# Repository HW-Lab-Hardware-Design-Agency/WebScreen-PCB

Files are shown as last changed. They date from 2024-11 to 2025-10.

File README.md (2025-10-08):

   

# WebScreen-PCB

WebScreen-PCB is the design of a printed circuit board (PCB) for the WebScreen, a display device with a custom stand. This project is developed by **HW Lab - Hardware Design Agency** and aims to optimize the integration and functionality of the WebScreen in various applications.



## Main Features
- **Optimized Design**: Compact and efficient PCB. 
- **Mounting System**: Insertion and friction-based fastening, eliminating the need for adhesives. 
- **Compatibility**: Designed to work with the [DO0200FS01 display](https://www.dwo.net.cn/pd.jsp?id=11919).
- **Connectivity**: Interfaces adapted for easy integration with other devices.
  
## Technical Specifications
- **Size**: 60.6 x 27.6 mm
- **Material**: FR-4 S1000H TG150
- **PCB Thickness**: 1.6 mm
- **Number of Layers**: 4 layers
- **Operating Voltage**: 5V (via usb)
- **Connection Interfaces**: USB / Wi-Fi / Bluetooth

## Included Files
- **Schematic**: : Circuit design in [KiCad](https://www.kicad.org/) format. 
- **PCB Layout**: Board design in Gerber format.
- **Bill of Materials (BOM)**: List of components used. 

## Installation and Usage  
1. Download the Gerber files and send them to a PCB manufacturer.  
2. Acquire the components according to the BOM.  
3. Assemble the PCB.  
4. [Integrate the PCB with the WebScreen](https://www.youtube.com/watch?v=CHH5L84EN5o&t=6s) and perform the corresponding tests.

## License
This project is open source. See the [LICENSE](https://github.com/HW-Lab-Hardware-Design-Agency/WebScreen-PCB/blob/main/LICENSE) file for details.

## PCBWay
[PCBWay](https://pcbway.com/g/j8T652) top quality PCBA service made this project possible: fast, precise, and super reliable. We highly recommend them to all creators out there, and we’ll definitely keep working with them for future builds.

## Contact
For inquiries or contributions, please contact the development team through the repository issues or via email.



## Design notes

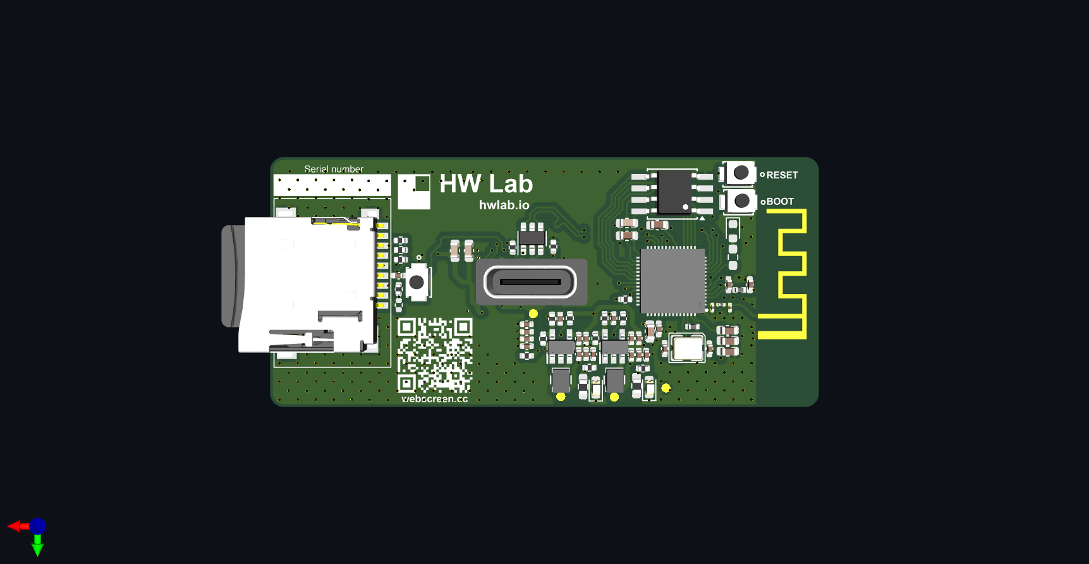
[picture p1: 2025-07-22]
WebScreen-pcba_layout_render.png

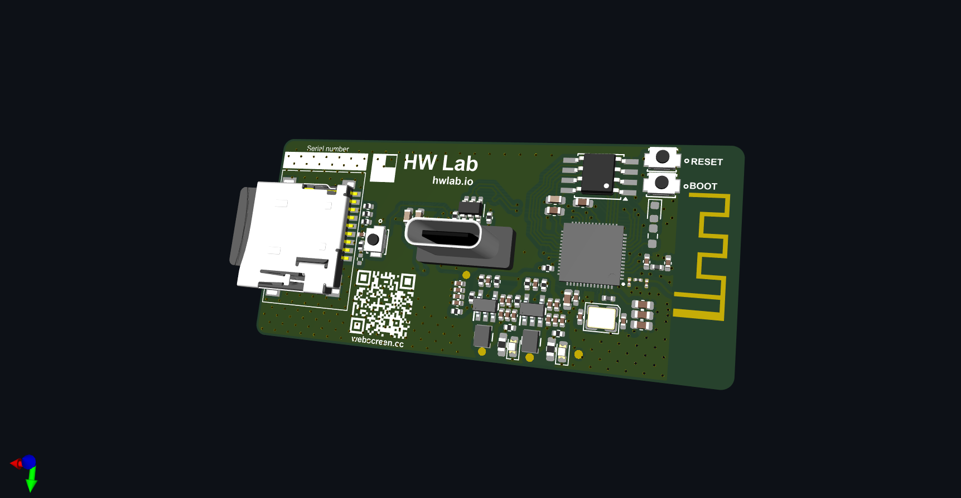
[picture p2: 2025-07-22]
WebScreen-pcba_layout_render_perspective.png

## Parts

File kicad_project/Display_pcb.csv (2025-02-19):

Reference | Value | Qty | DNP | BOM | LCSC Part # | MPN
AE1 | PCB Antenna 2.4GHz | 1
C1,C8,C9,C12,C13,C19,C23,C26,C29,C35 | 100nF | 10 |  | 35V 100nF X7R ±10% 0402 Multilayer Ceramic Capacitors MLCC - SMD/SMT ROHS | C343047 | CGA2B3X7R1V104KT0Y0F
C2,C5,C6,C7,C10,C14,C15,C20,C32,C33 | 1uF | 10 |  | 16V 1uF X5R ±10% 0603 Multilayer Ceramic Capacitors MLCC - SMD/SMT ROHS | C1592 | CL10A105KO8NNNC
C3 | 15pF | 1 |  | 16V 15pF NP0 ±10% 0402 Multilayer Ceramic Capacitors MLCC - SMD/SMT ROHS | C1852854 | CC0402KRNPO7BN150
C4 | 12pF | 1 |  | 25V 12pF null ±2% 0402 Multilayer Ceramic Capacitors MLCC - SMD/SMT ROHS | C882545 | GRM1555C1E120GA01D
C11,C18 | 10uF | 2 |  | 10V 10uF X5R ±20% 0402 Multilayer Ceramic Capacitors MLCC - SMD/SMT ROHS | C315248 | CL05A106MP5NUNC
C16,C17 | 1.8pF | 2 |  | 50V 1.8pF C0G 0201 Multilayer Ceramic Capacitors MLCC - SMD/SMT ROHS | C161415 | GRM0335C1H1R8BA01D
C21,C31 | 6.8pF | 2 |  | 50V 6.8pF C0G 0402 Multilayer Ceramic Capacitors MLCC - SMD/SMT ROHS | C1576 | 0402CG6R8C500NT
C22,C24,C25,C30,C34,C36 | 22uF | 6 |  | 10V 22uF X5R ±20% 0402 Multilayer Ceramic Capacitors MLCC - SMD/SMT ROHS | C6119813 | CGA0402X5R226M100GT
DS1,DS2,DS3 | GREEN | 3 |  | LED GREEN [0603] | C125098 | LTST-C191KGKT
IC1 | ESP32-S3R8 | 1 |  | WiFi Modules - 802.11 SMD IC, Dual-Core MCU, Wi-Fi 2.4G & BLE 5.0 Combo, 8 MB Octal SPI PSRAM, QFN 56-pin, 7*7 mm | C2913194 | ESP32-S3R8
J1 | Micro_SD_Card_Det_Hirose_DM3AT | 1 |  | -20℃~+90℃ 2mm Deck MicroSD card (TF card) Self bomb SMD SD Card / Memory Card Connector ROHS | C393941 | TF PUSH
J2 | USB C | 1 |  |  | C2894918 | HC019-1E1H1A103-0HR
J8 | 33FXRH-SM1-GAN-TF | 1 |  | SMD,P=0.6mm FFC/FPC Connectors ROHS | C2890488 | 33FXRH-SM1-GAN-TF
L1 | 22nH | 1 |  | 300mA 22nH ±5% 600mΩ 0402 Inductors (SMD) ROHS | C15178 | SDCL1005C22NJTDF
L2 | 2nH | 1 |  | 300mA 2nH 200mΩ 0402 Inductors (SMD) ROHS | C279790 | SDCL1005C2N0BTDF
L3 | 2.7nH | 1 |  | 500mA 2.7nH 200mΩ 0201 Inductors (SMD) ROHS | C98043 | LQP03TN2N7B02D
L4,L5 | 1uH | 2 |  | 1.2A 1uH ±20% 1.2A 1007 Power Inductors ROHS | C524998 | BRFL2518T1R0M
Q1,Q3 | S8050 | 2 |  | 25V 300mW 500mA NPN SOT-23 Bipolar (BJT) ROHS | C181158 | S8050
Q2 | BSS84 | 1 |  | 50V 130mA 200mW 10Ω@5V,100mA 2.5V@250uA 1 Piece P-Channel SOT-23 MOSFETs ROHS | C2926187 | IRF4905STRLP(UMW)
R1,R2,R3,R4,R12 | 10k | 5 |  | 62.5mW Thick Film Resistors 50V ±100ppm/℃ ±5% 10kΩ 0402 Chip Resistor - Surface Mount ROHS | C25531 | 0402WGJ0103TCE
R5,R6 | 4k99 | 2 |  | 62.5mW Thick Film Resistors 50V ±100ppm/℃ ±1% 4.99kΩ 0402 Chip Resistor - Surface Mount ROHS | C137965 | RC0402FR-074K99L
R7,R11,R13,R14,R30 | 100k | 5 |  | 62.5mW Thick Film Resistors 50V ±100ppm/℃ ±1% 100kΩ 0402 Chip Resistor - Surface Mount ROHS | C25741 | 0402WGF1003TCE
R9,R10 | TBD | 2
R15,R16,R23 | 1k | 3 |  | RES SMD 1k 1% [0603] | C844746 | CRCW06031K00FKEAC
R17 | 22k | 1 |  | 62.5mW Thick Film Resistors 50V ±100ppm/℃ ±1% 22kΩ 0402 Chip Resistor - Surface Mount ROHS | C25768 | 0402WGF2202TCE
R18,R19,R21,R32 | 0R | 4 |  | 62.5mW Thick Film Resistors 50V ±800ppm/℃ ±1% 0Ω 0402 Chip Resistor - Surface Mount ROHS | C17168 | 0402WGF0000TCE
R31 | 680k | 1 |  | 62.5mW Thick Film Resistors 50V ±100ppm/℃ ±1% 680kΩ 0402 Chip Resistor - Surface Mount ROHS | C163456 | RC0402FR-07680KL
SW1,SW2,SW3 | B3U-1000P | 3 |  | 2.5mm 1.6mm Round Button 50mA Brick nogging 3mm SPST 153gf 12V SMD,2.5x3mm Tactile Switches ROHS | C231329 | B3U-1000P
U1 | W25Q128JVSIQ | 1 |  | 128Mbit SOIC-8-208mil NOR FLASH ROHS | C113767 | W25Q128JVSIQ
U2,U4 | SY8089A1AAC | 2 |  | LOW LOSS POWER DISTRIBUTION SWITCH WITH | C479074 | SY8089A1AAC
U5 | USBLC6-2SC6 | 1 |  | 5A 17V 6V Unidirectional 5.25V SOT-23-6 Electrostatic and Surge Protection (TVS/ESD) ROHS | C7519 | USBLC6-2SC6
Y1 | 40MHz | 1 |  | 40MHz 贴片晶振 15pF ±10ppm ±20ppm SMD3225-4P Crystals ROHS | C9010 | X322540MPB4SI

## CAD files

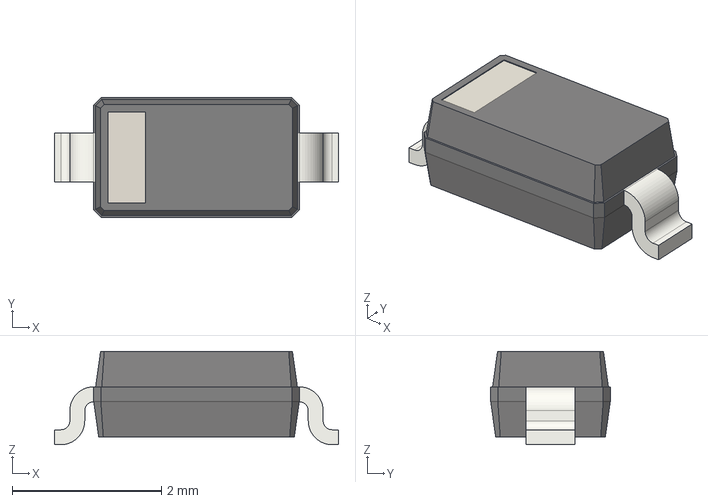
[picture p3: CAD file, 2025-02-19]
kicad_project/3Dlib/D_SOD-123.step
3.80 x 1.60 x 1.25 mm

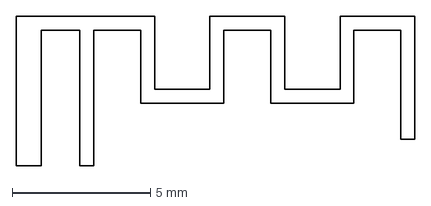
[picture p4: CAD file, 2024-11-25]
kicad_project/design_pcb_antenna/pcb_antenna_2-4GHz.dxf
14.4 x 5.40 mm

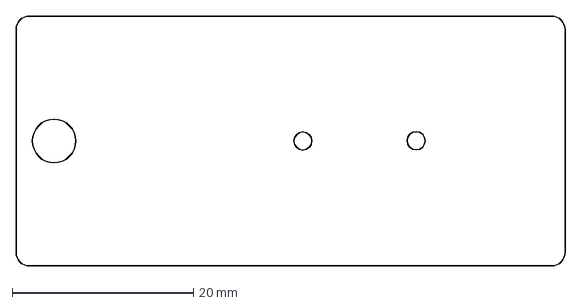
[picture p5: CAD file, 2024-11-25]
kicad_project/pcb_outline.dxf
60.6 x 27.6 mm

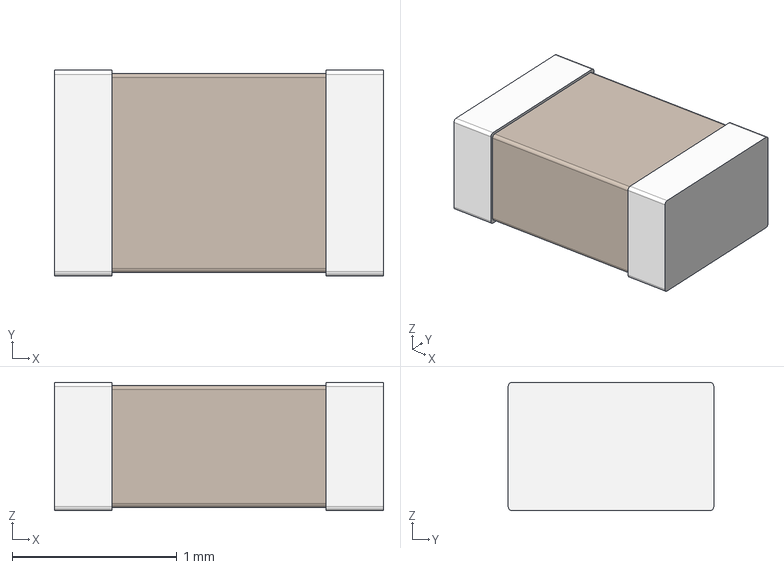
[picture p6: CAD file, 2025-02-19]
kicad_project/3Dlib/c_0805_h078.step
2.00 x 1.25 x 0.78 mm

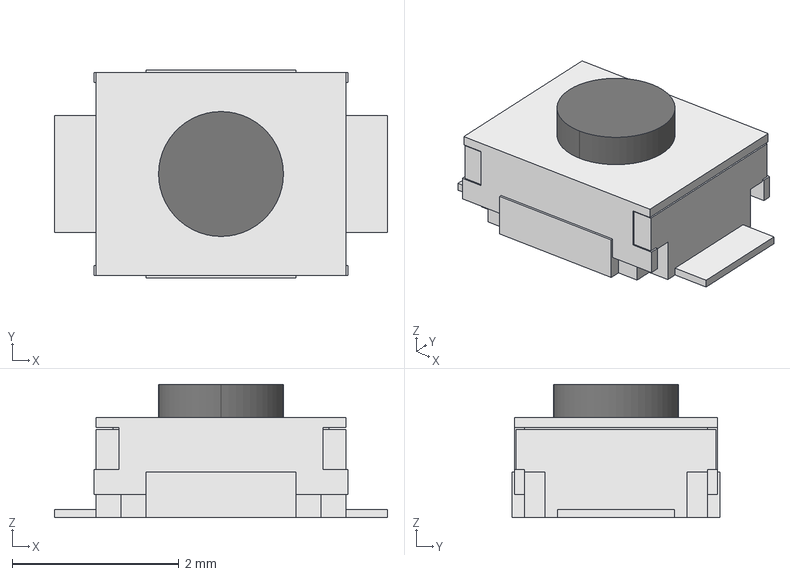
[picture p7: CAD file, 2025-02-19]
kicad_project/3Dlib/B3U_1000P.step
4.00 x 2.50 x 1.60 mm

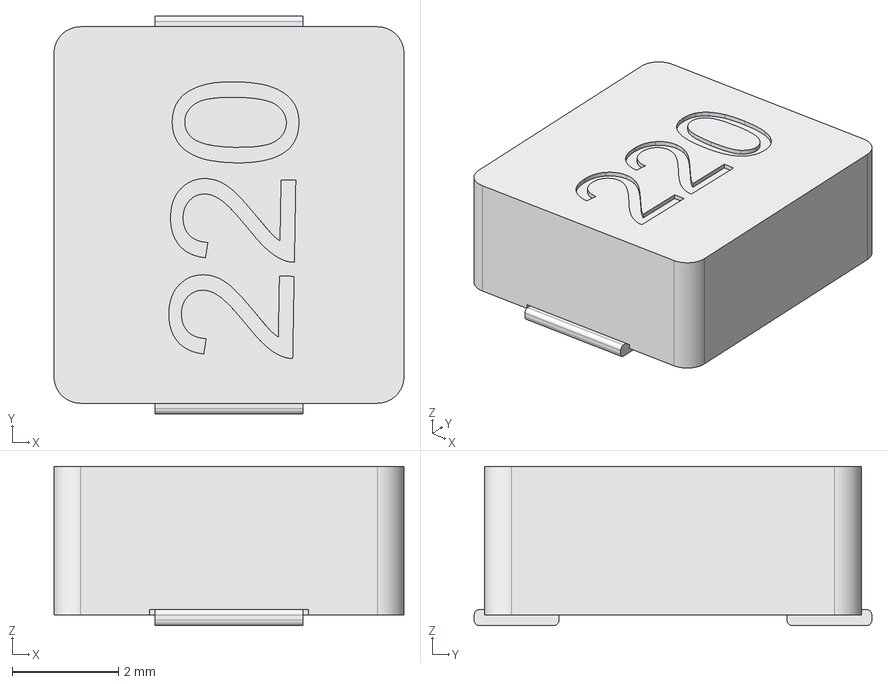
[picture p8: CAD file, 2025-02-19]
kicad_project/3Dlib/MDA7030-220M.step
6.60 x 7.50 x 3.00 mm

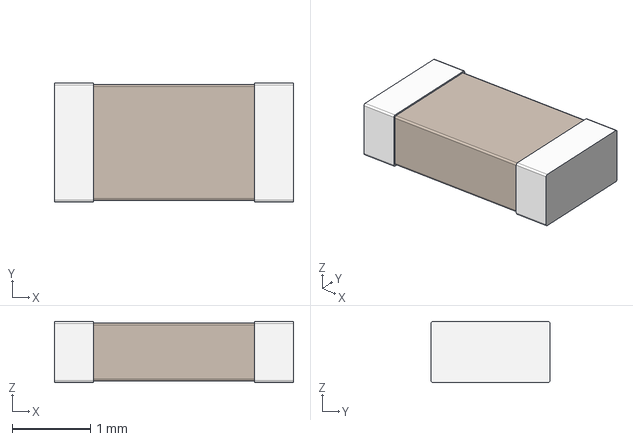
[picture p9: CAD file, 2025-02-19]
kicad_project/3Dlib/c_1206_h078.step
3.05 x 1.52 x 0.78 mm

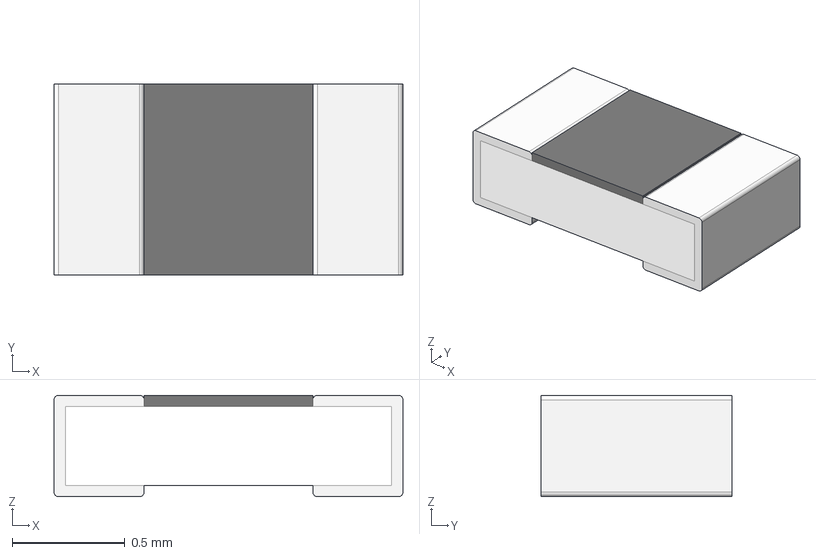
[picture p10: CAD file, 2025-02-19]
kicad_project/3Dlib/r_0603_h078.step
1.55 x 0.85 x 0.45 mm

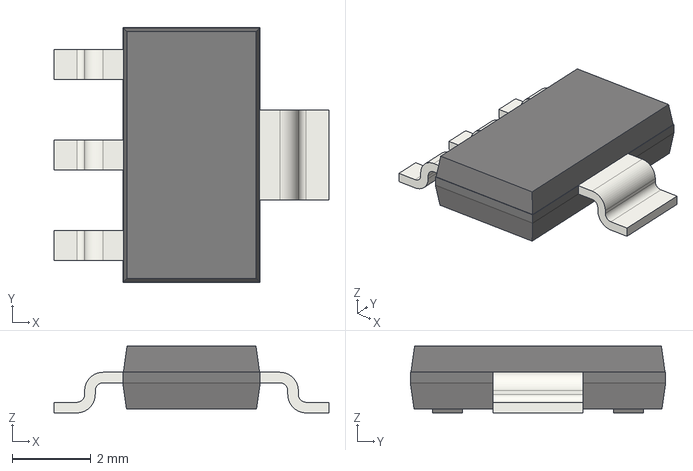
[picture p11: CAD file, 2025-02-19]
kicad_project/3Dlib/SOT-223.step
7.00 x 6.50 x 1.70 mm

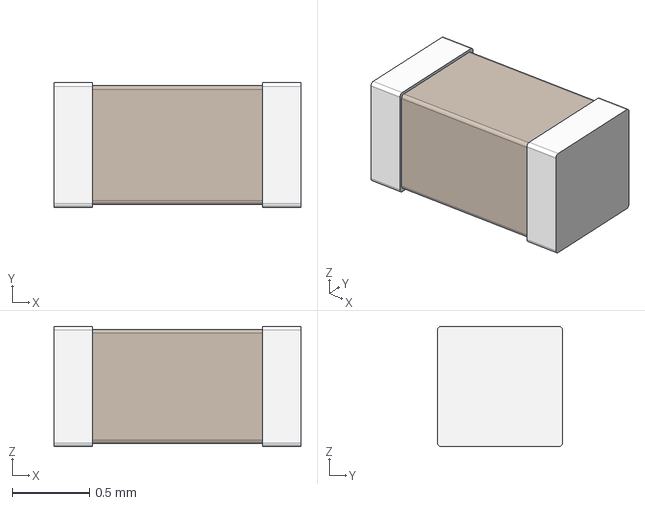
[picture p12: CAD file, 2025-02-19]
kicad_project/3Dlib/c_0603_h078.step
1.60 x 0.81 x 0.78 mm

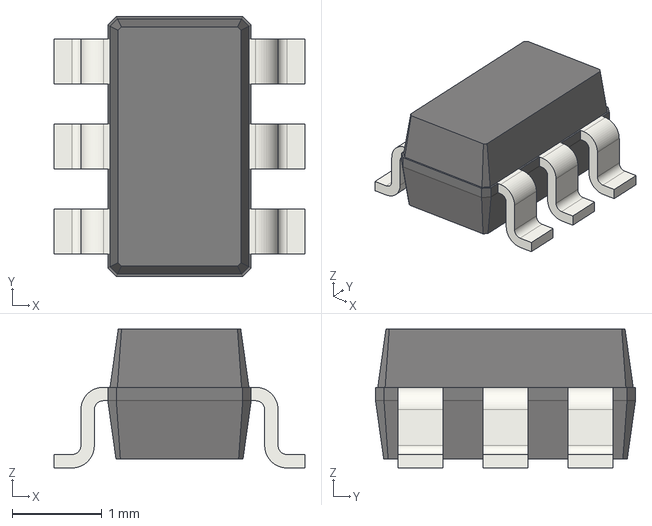
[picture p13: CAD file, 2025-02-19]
kicad_project/3Dlib/SOT-23-6.step
2.80 x 2.90 x 1.55 mm

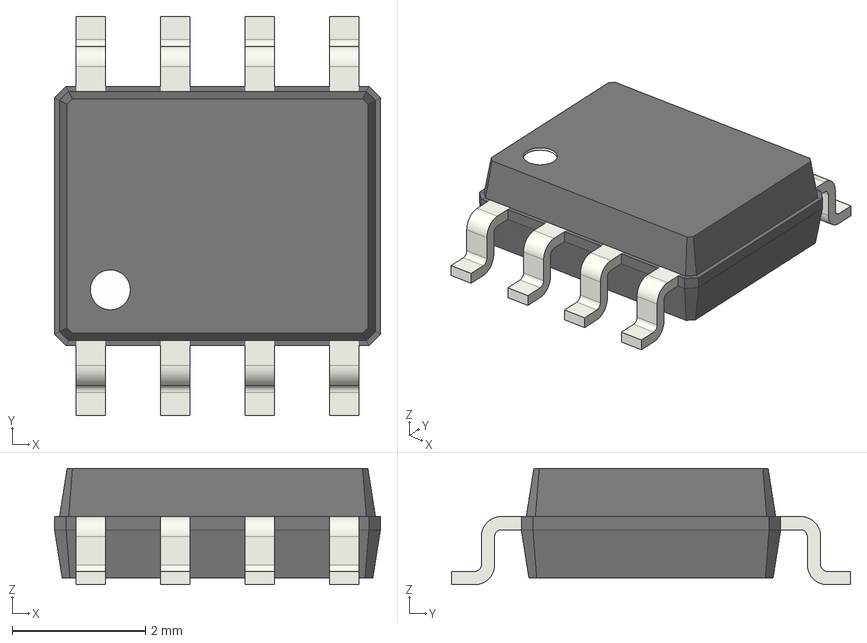
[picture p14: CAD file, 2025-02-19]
kicad_project/3Dlib/soic_8_39x49_p127.step
4.90 x 6.00 x 1.75 mm

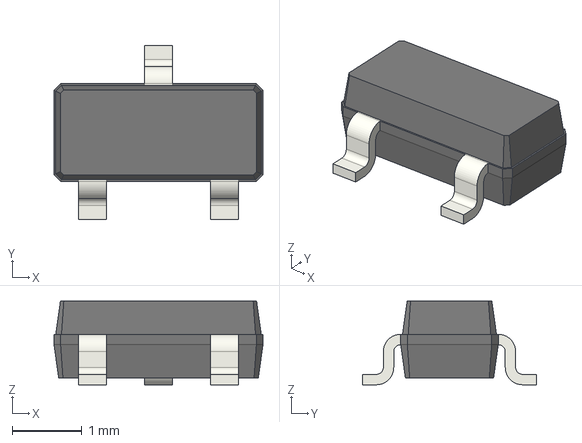
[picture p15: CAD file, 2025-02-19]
kicad_project/3Dlib/sot23_3_25x30_p095.step
3.00 x 2.50 x 1.20 mm

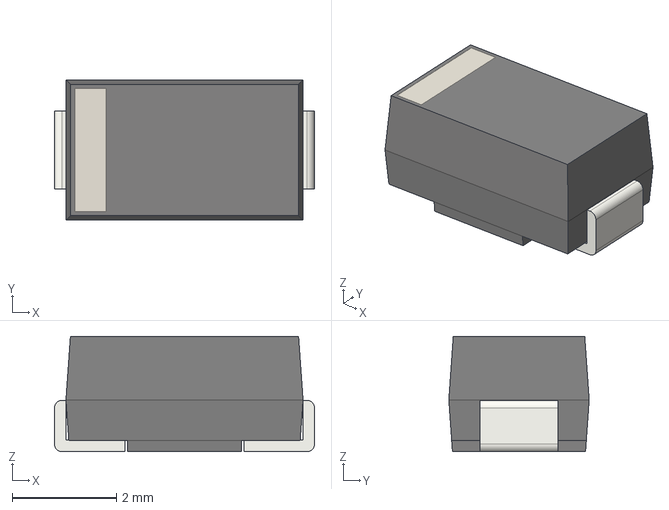
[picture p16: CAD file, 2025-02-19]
kicad_project/3Dlib/D_SMA.step
5.00 x 2.70 x 2.22 mm

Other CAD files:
kicad_project/design_pcb_antenna/antenna_footprint.FCStd
kicad_project/3Dlib/MicroSD_Socket.STEP
kicad_project/3Dlib/33FXRH-SM1-GAN-TF.STEP
kicad_project/3Dlib/L_0201_0603Metric.step
kicad_project/3Dlib/AXPM65611.step
kicad_project/3Dlib/BRFL2518T1R0M.STEP
kicad_project/3Dlib/C_0201_0603Metric.step
kicad_project/3Dlib/C_0402_1005Metric.step
kicad_project/3Dlib/Crystal_SMD_3225-4Pin_3.2x2.5mm.step
kicad_project/3Dlib/DFE252012P-1R0M=P2.STEP
kicad_project/3Dlib/ESP32-S3R8.stp
kicad_project/3Dlib/L_0402_1005Metric.step
kicad_project/3Dlib/SY8089A1AAC.stp
kicad_project/3Dlib/USB_C_HC019-1E1H1A103-0HR.step
kicad_project/3Dlib/c_1206_h160.step
kicad_project/3Dlib/c_1210.step
kicad_project/3Dlib/led_0603.step
kicad_project/3Dlib/r_0402_h040.step

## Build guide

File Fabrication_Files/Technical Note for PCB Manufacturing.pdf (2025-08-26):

Technical Note for PCB Manufacturing

Dear team,
Please take into consideration the following points regarding this design:
1. SD Card Reader
The SD card reader connector extends beyond the PCB outline. This condition is intentional and must be respected during assembly and quality control.

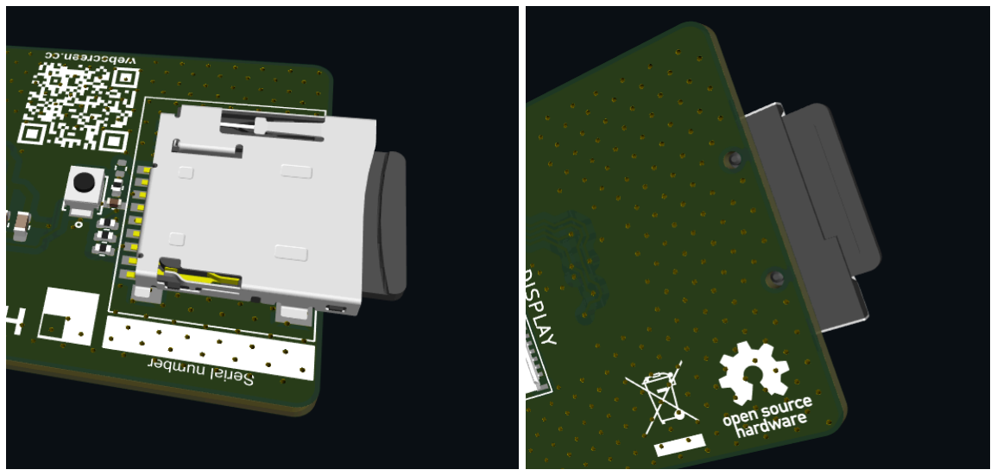
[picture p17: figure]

2. J8 Connector
The J8 connector includes two additional pads to ensure compatibility with similar connector models. These extra pads must be preserved and processed as standard pads, without modification.

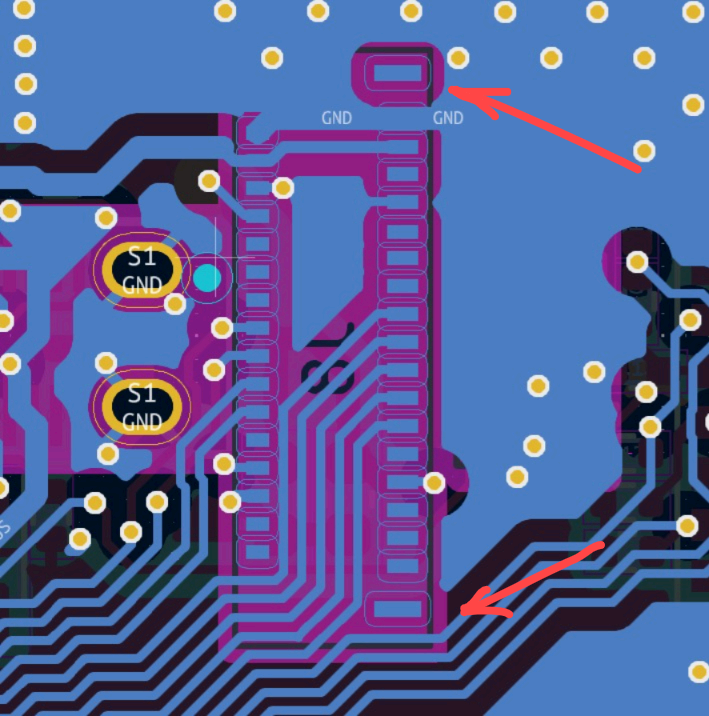
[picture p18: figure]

3. Antenna
The antenna area must remain free of solder and solder paste. In the manufacturing files, the F.Paste layer correctly indicates that no solder paste should be applied in this region. Please verify this before assembly.

### 4. Vias

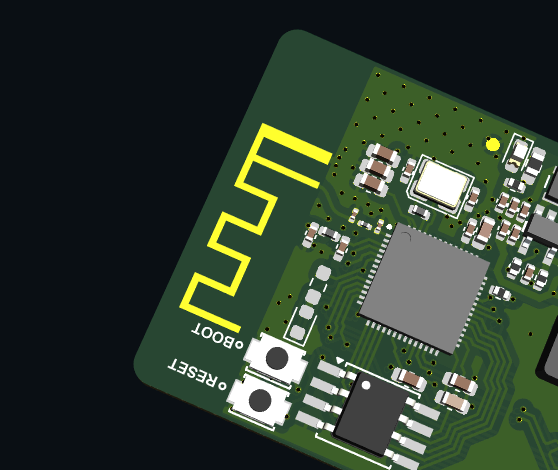
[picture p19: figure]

All vias must be resin-filled and capped to improve reliability and ensure proper solder mask coverage.

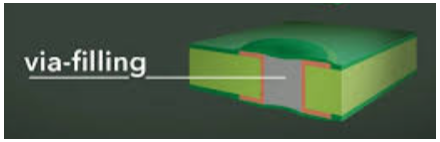
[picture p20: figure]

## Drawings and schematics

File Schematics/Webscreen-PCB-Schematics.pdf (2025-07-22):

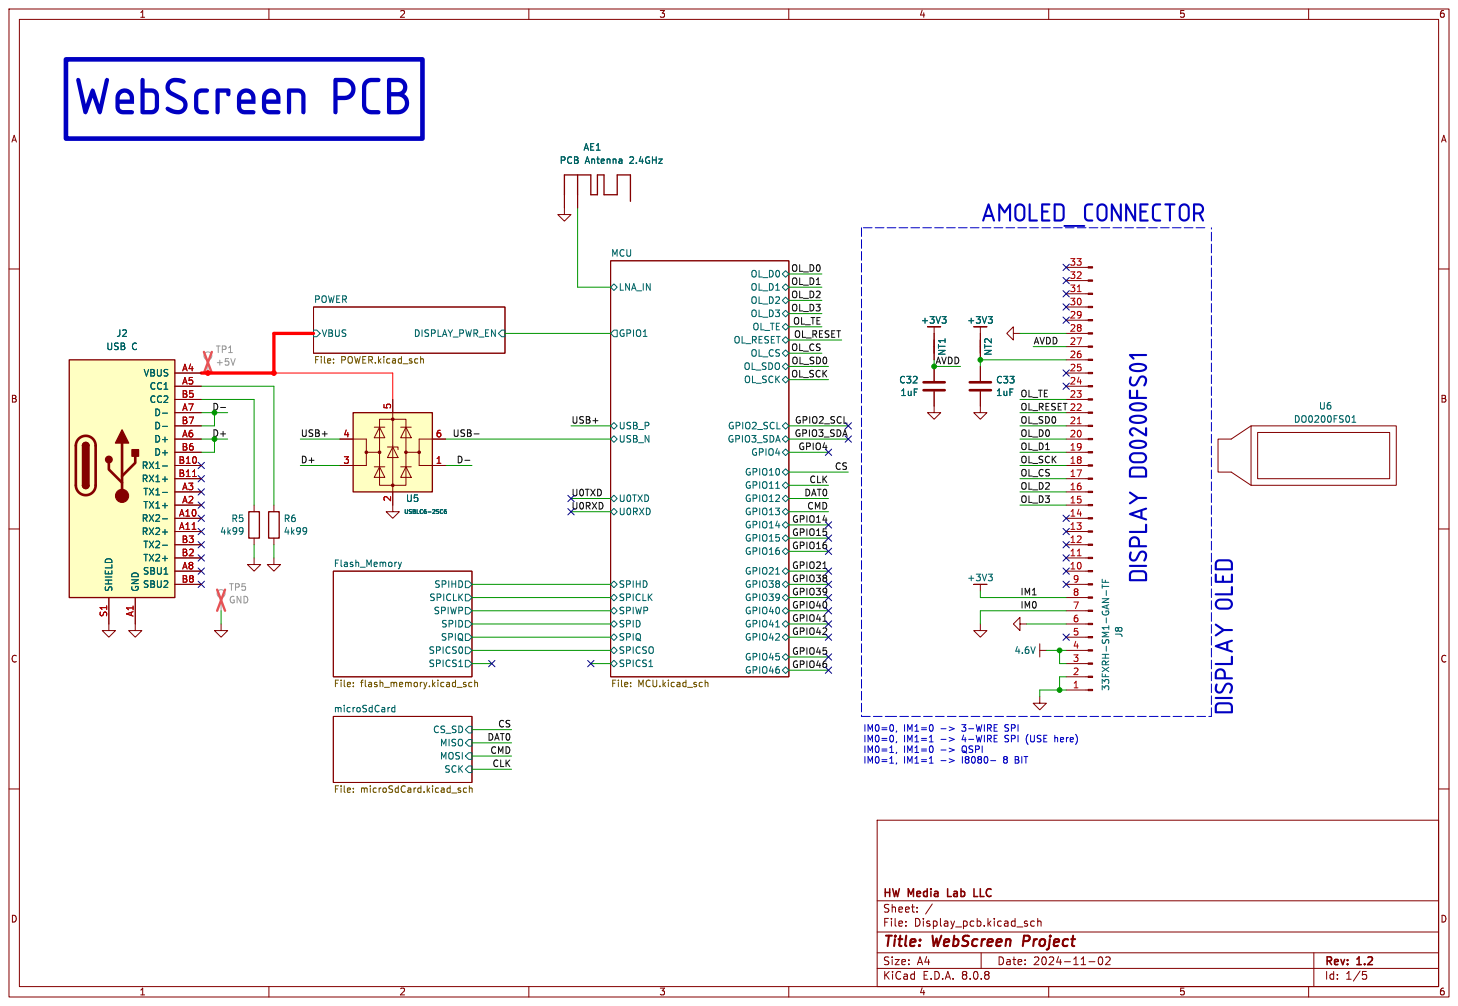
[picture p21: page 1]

CS_SD MOSI SCK MISO microSdCard File: microSdCard.kicad_sch

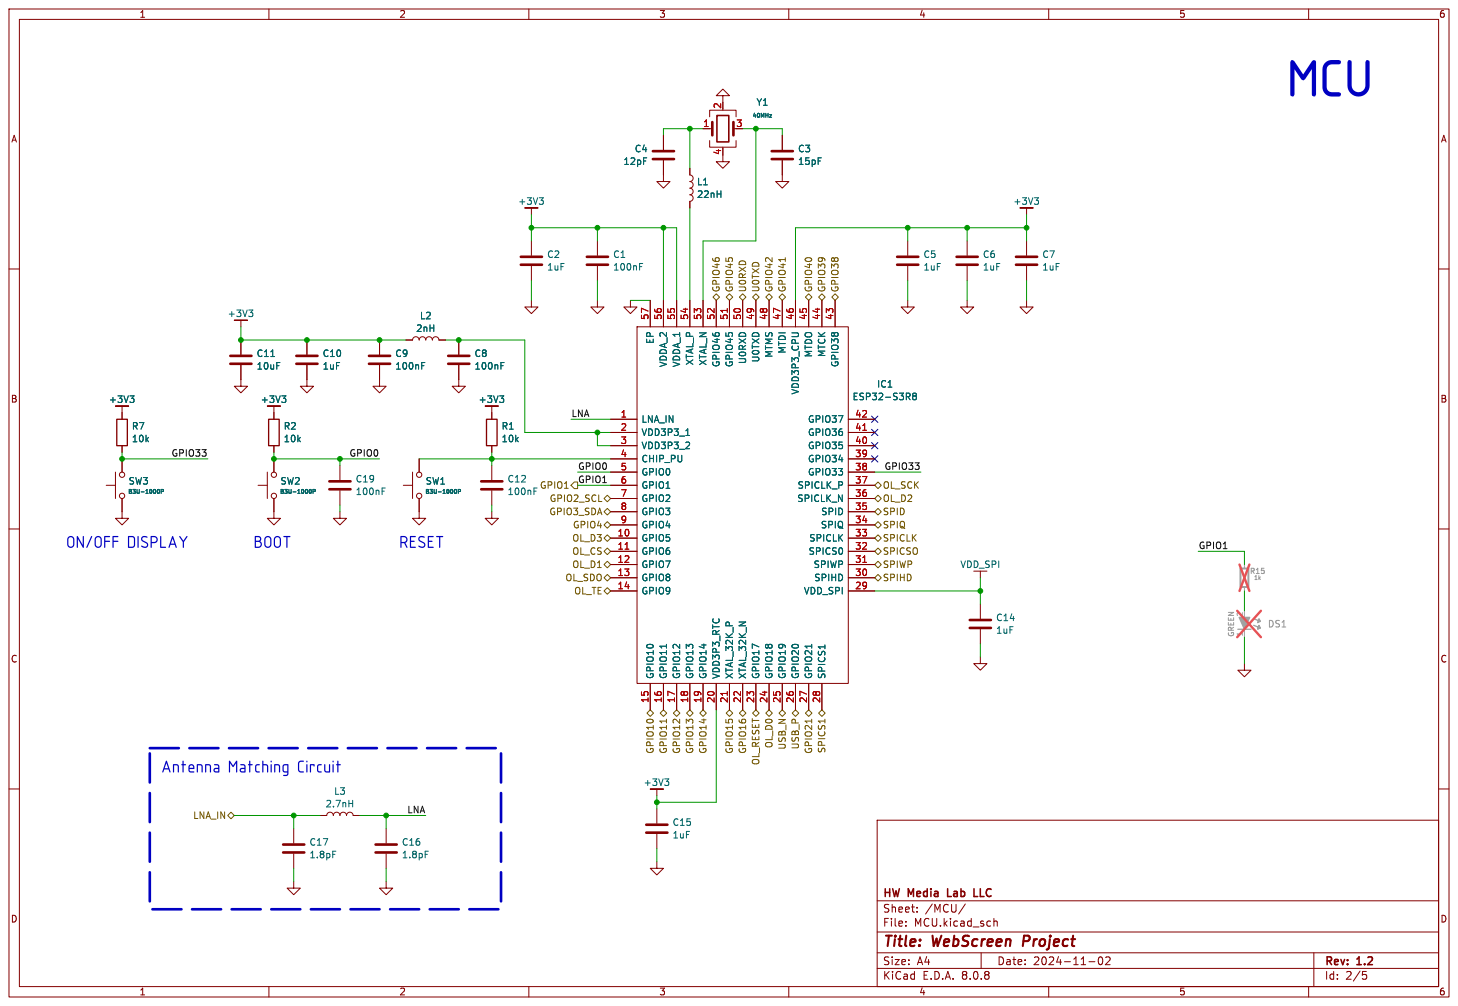
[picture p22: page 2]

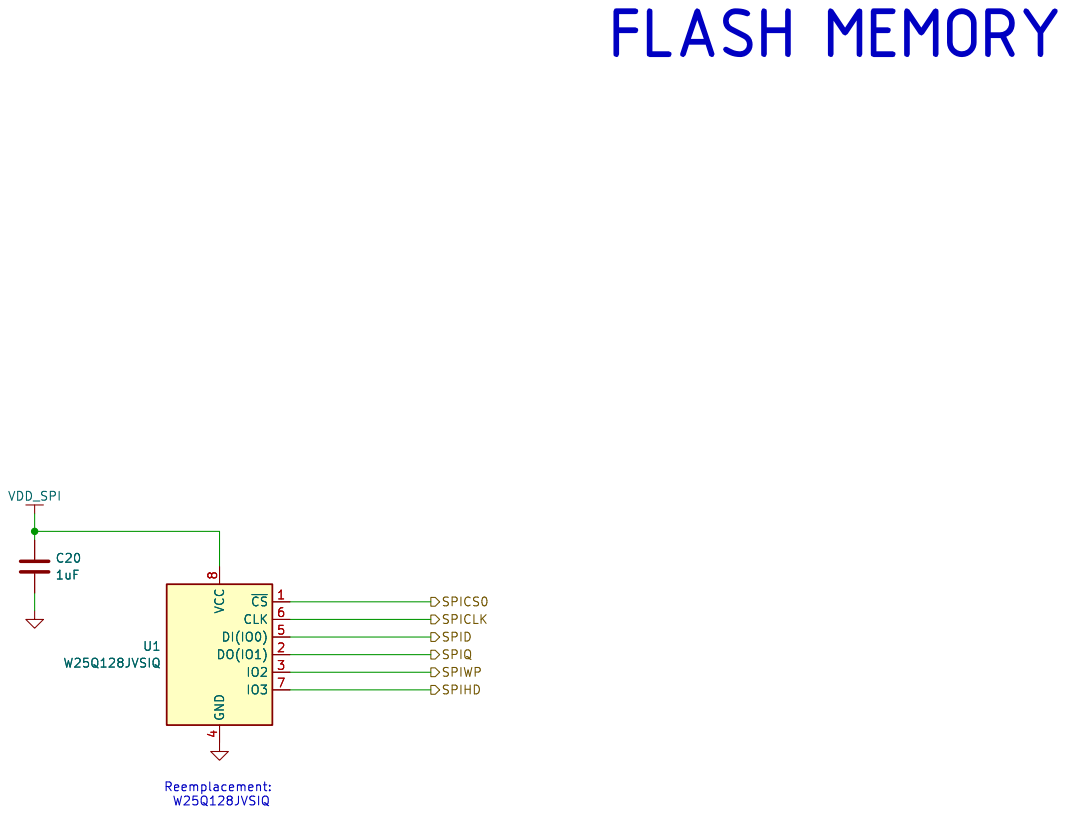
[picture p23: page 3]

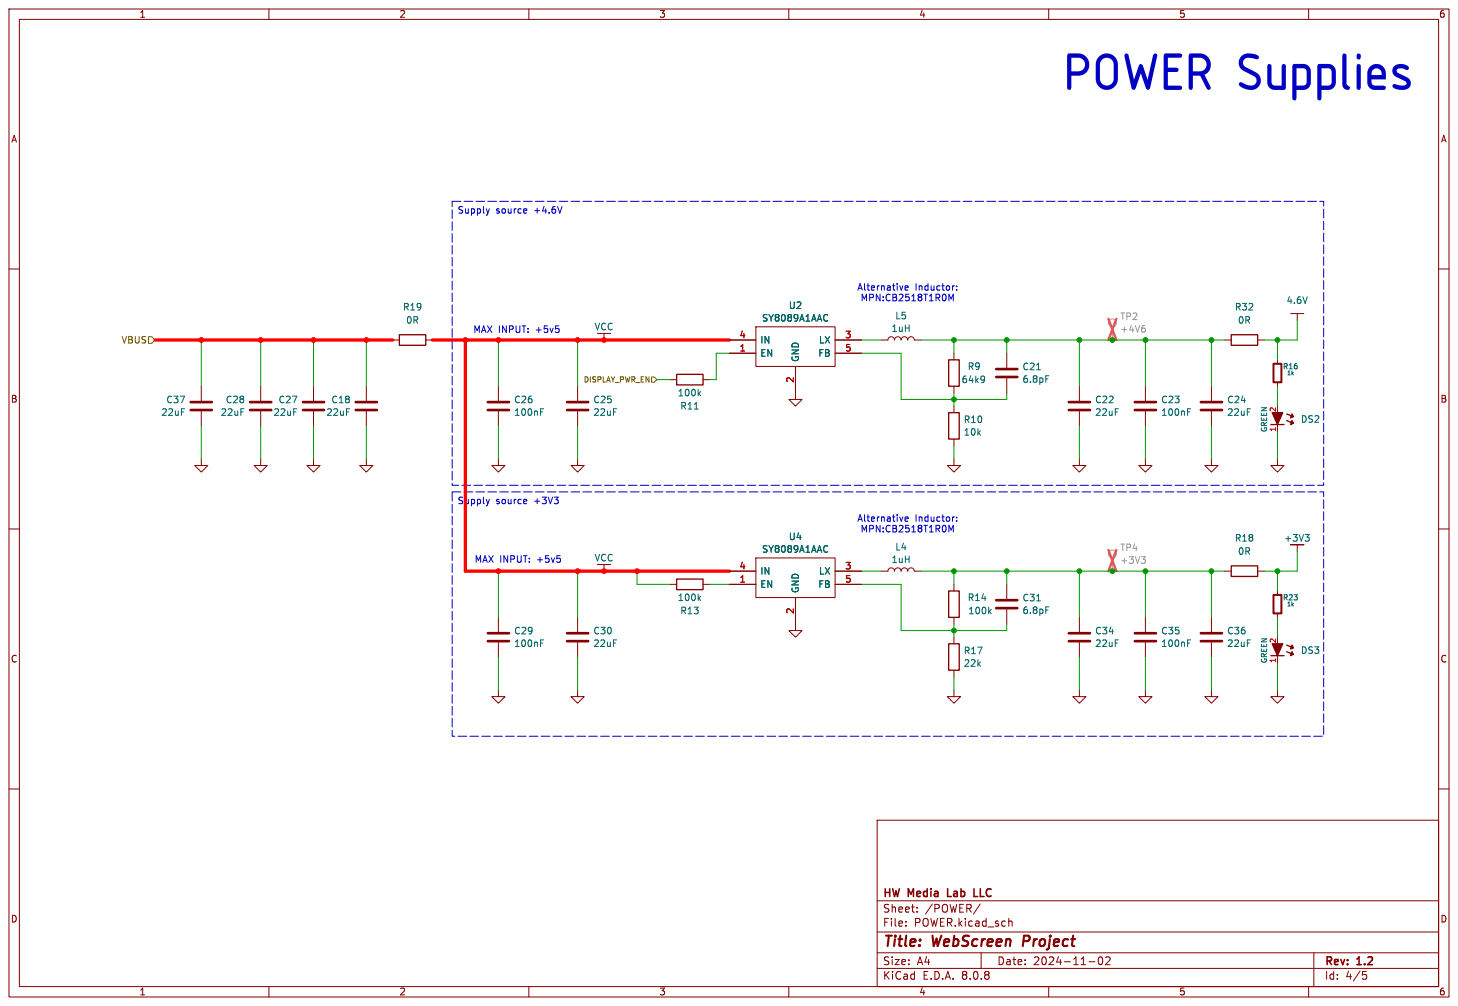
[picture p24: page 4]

MAX INPUT: +5v5

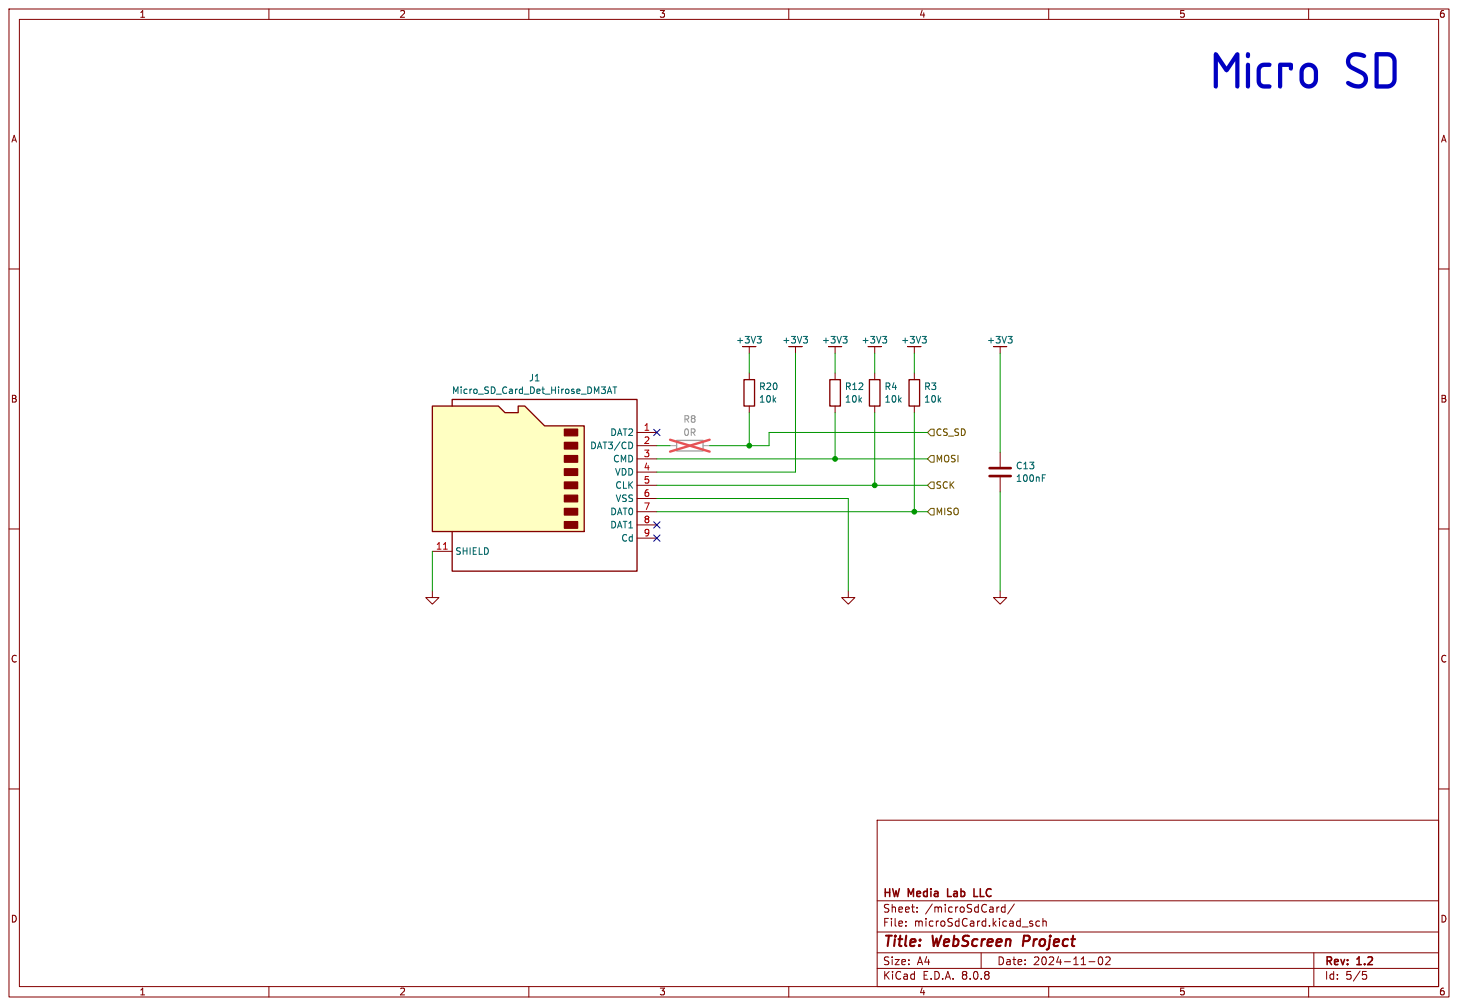
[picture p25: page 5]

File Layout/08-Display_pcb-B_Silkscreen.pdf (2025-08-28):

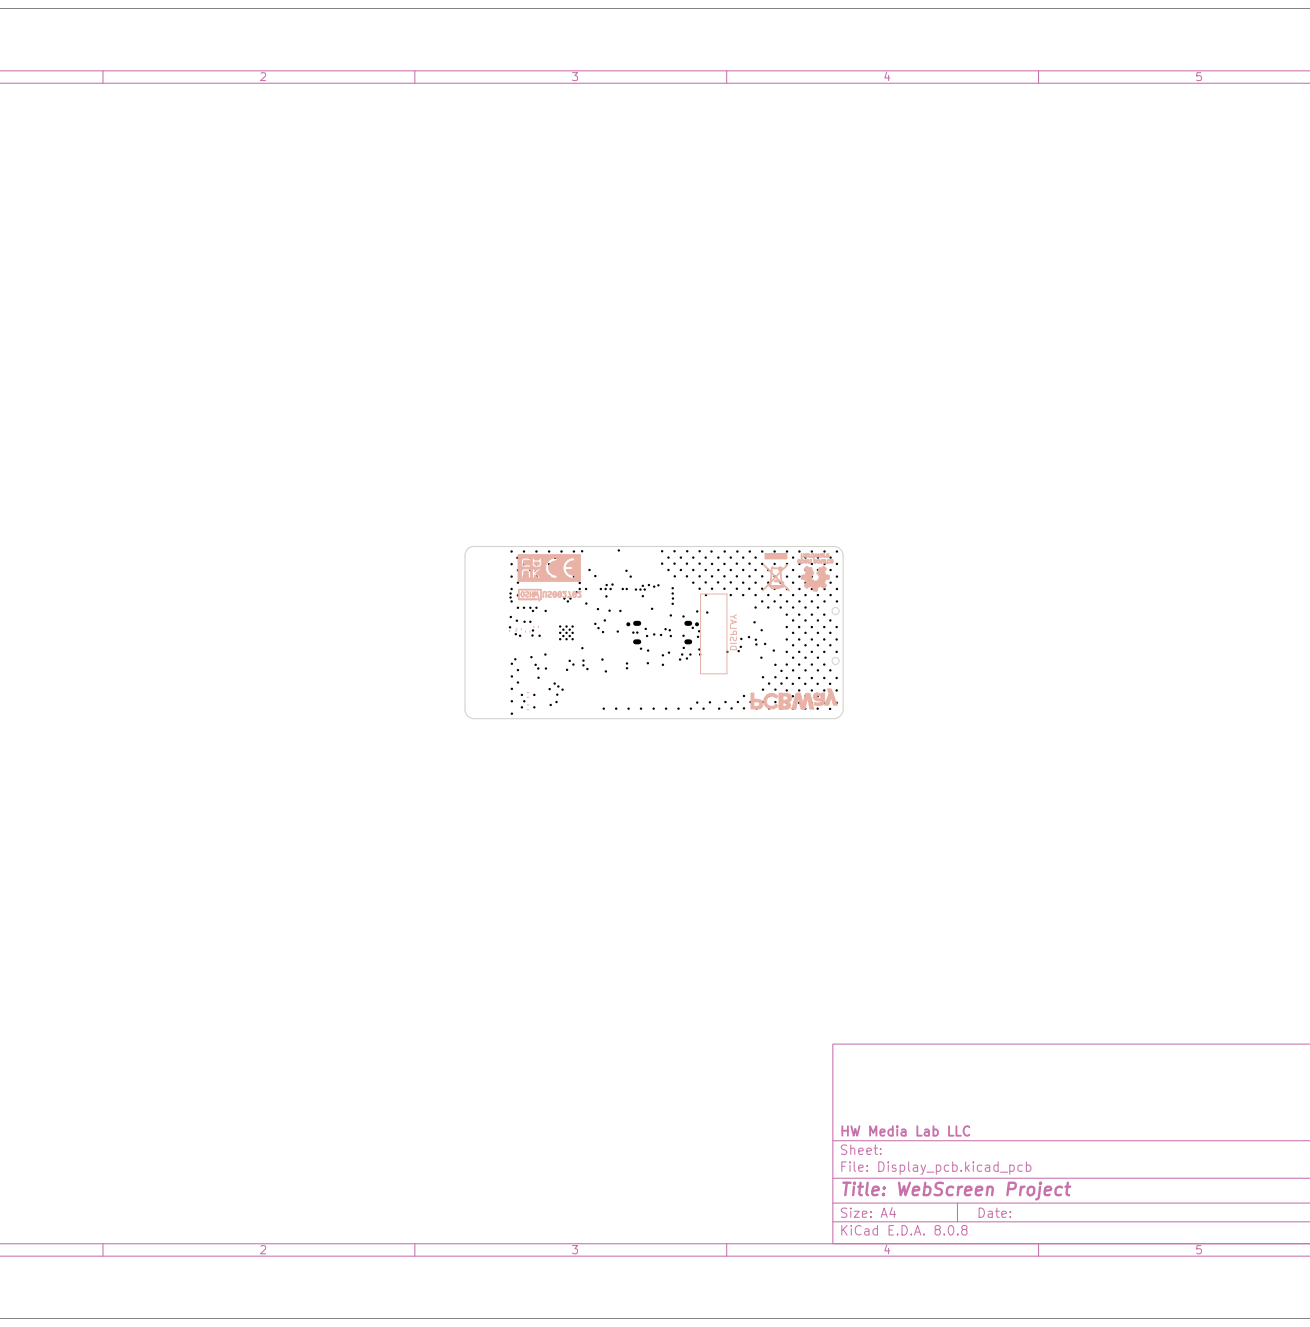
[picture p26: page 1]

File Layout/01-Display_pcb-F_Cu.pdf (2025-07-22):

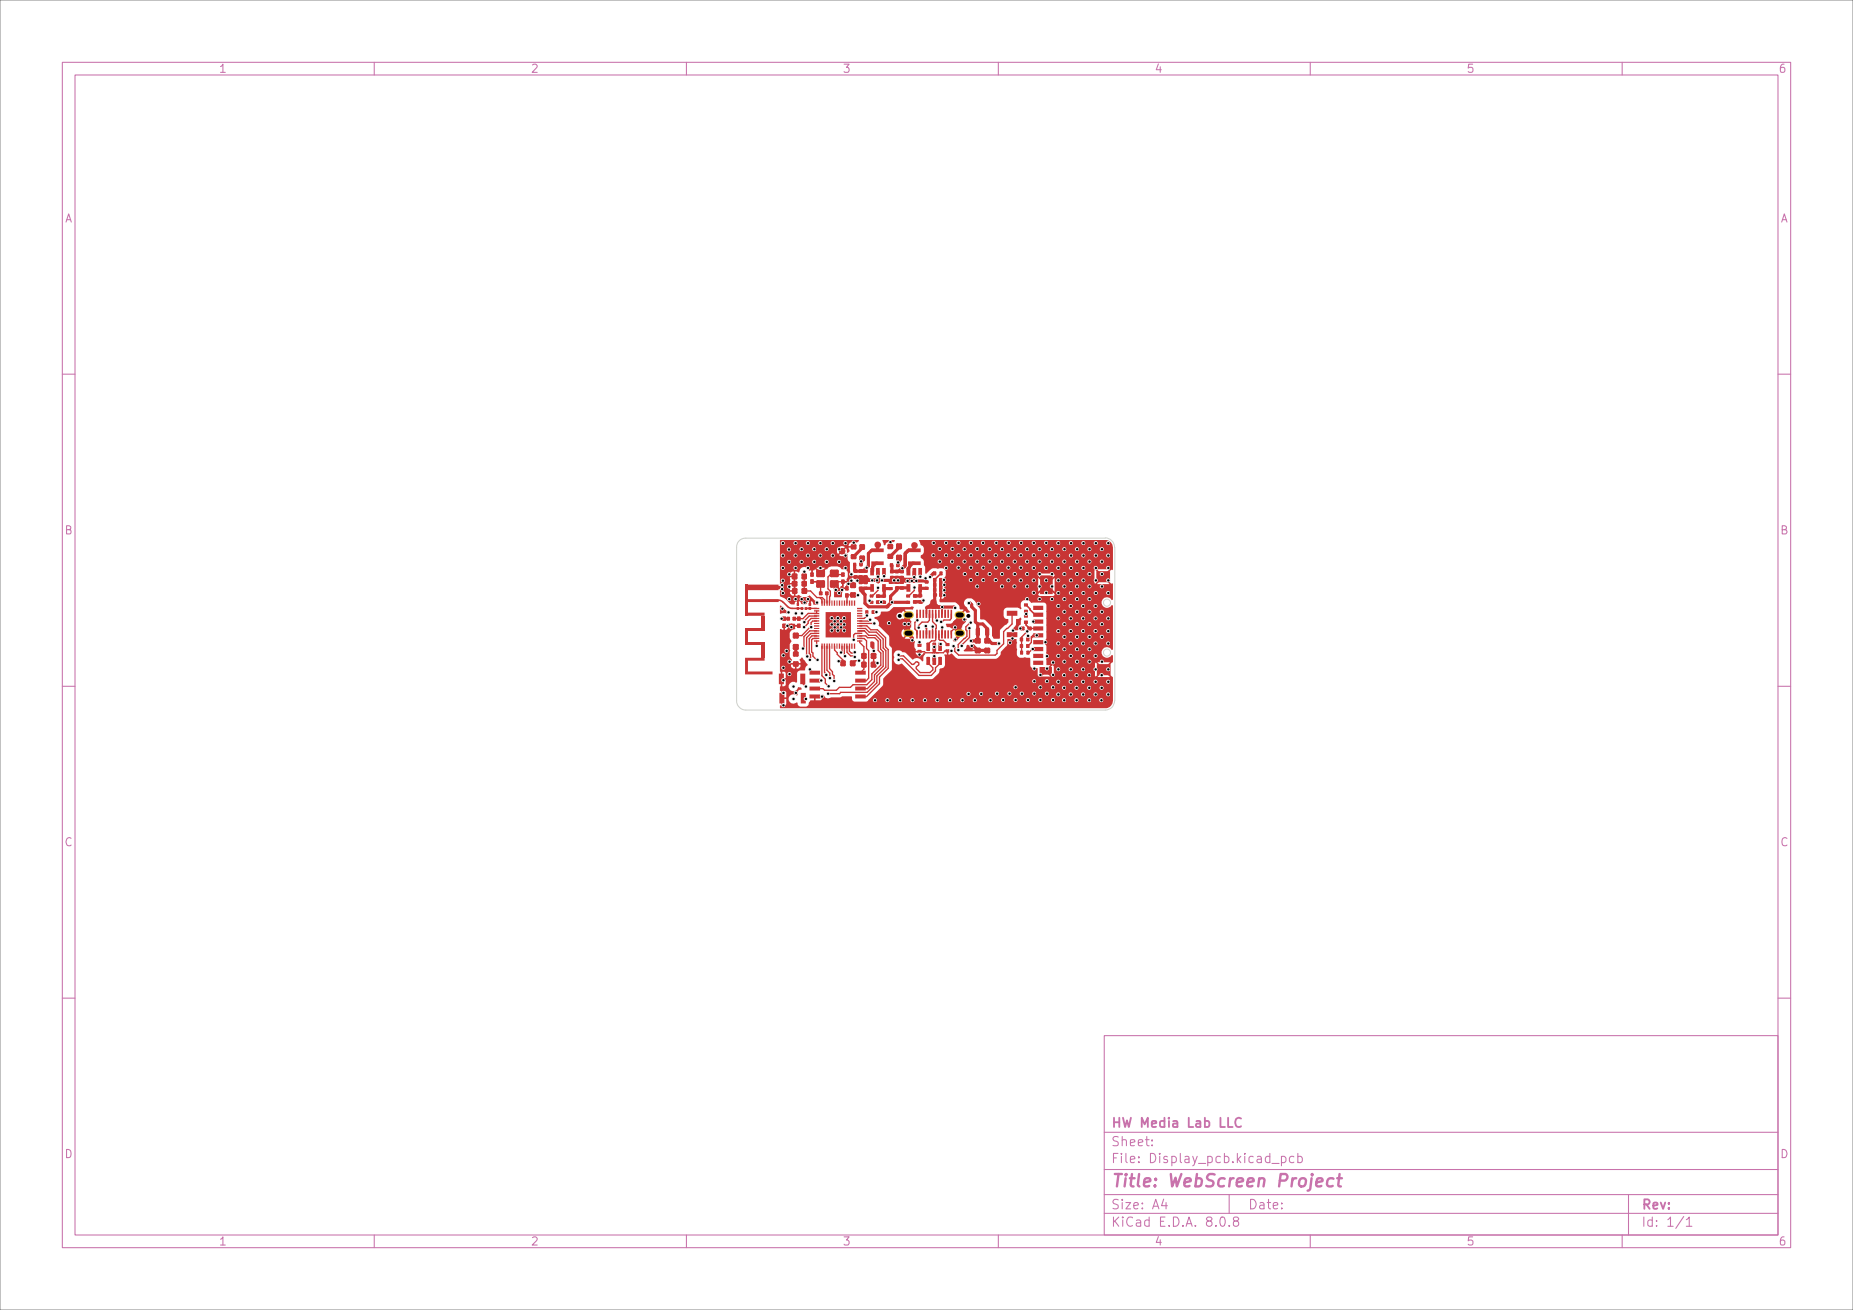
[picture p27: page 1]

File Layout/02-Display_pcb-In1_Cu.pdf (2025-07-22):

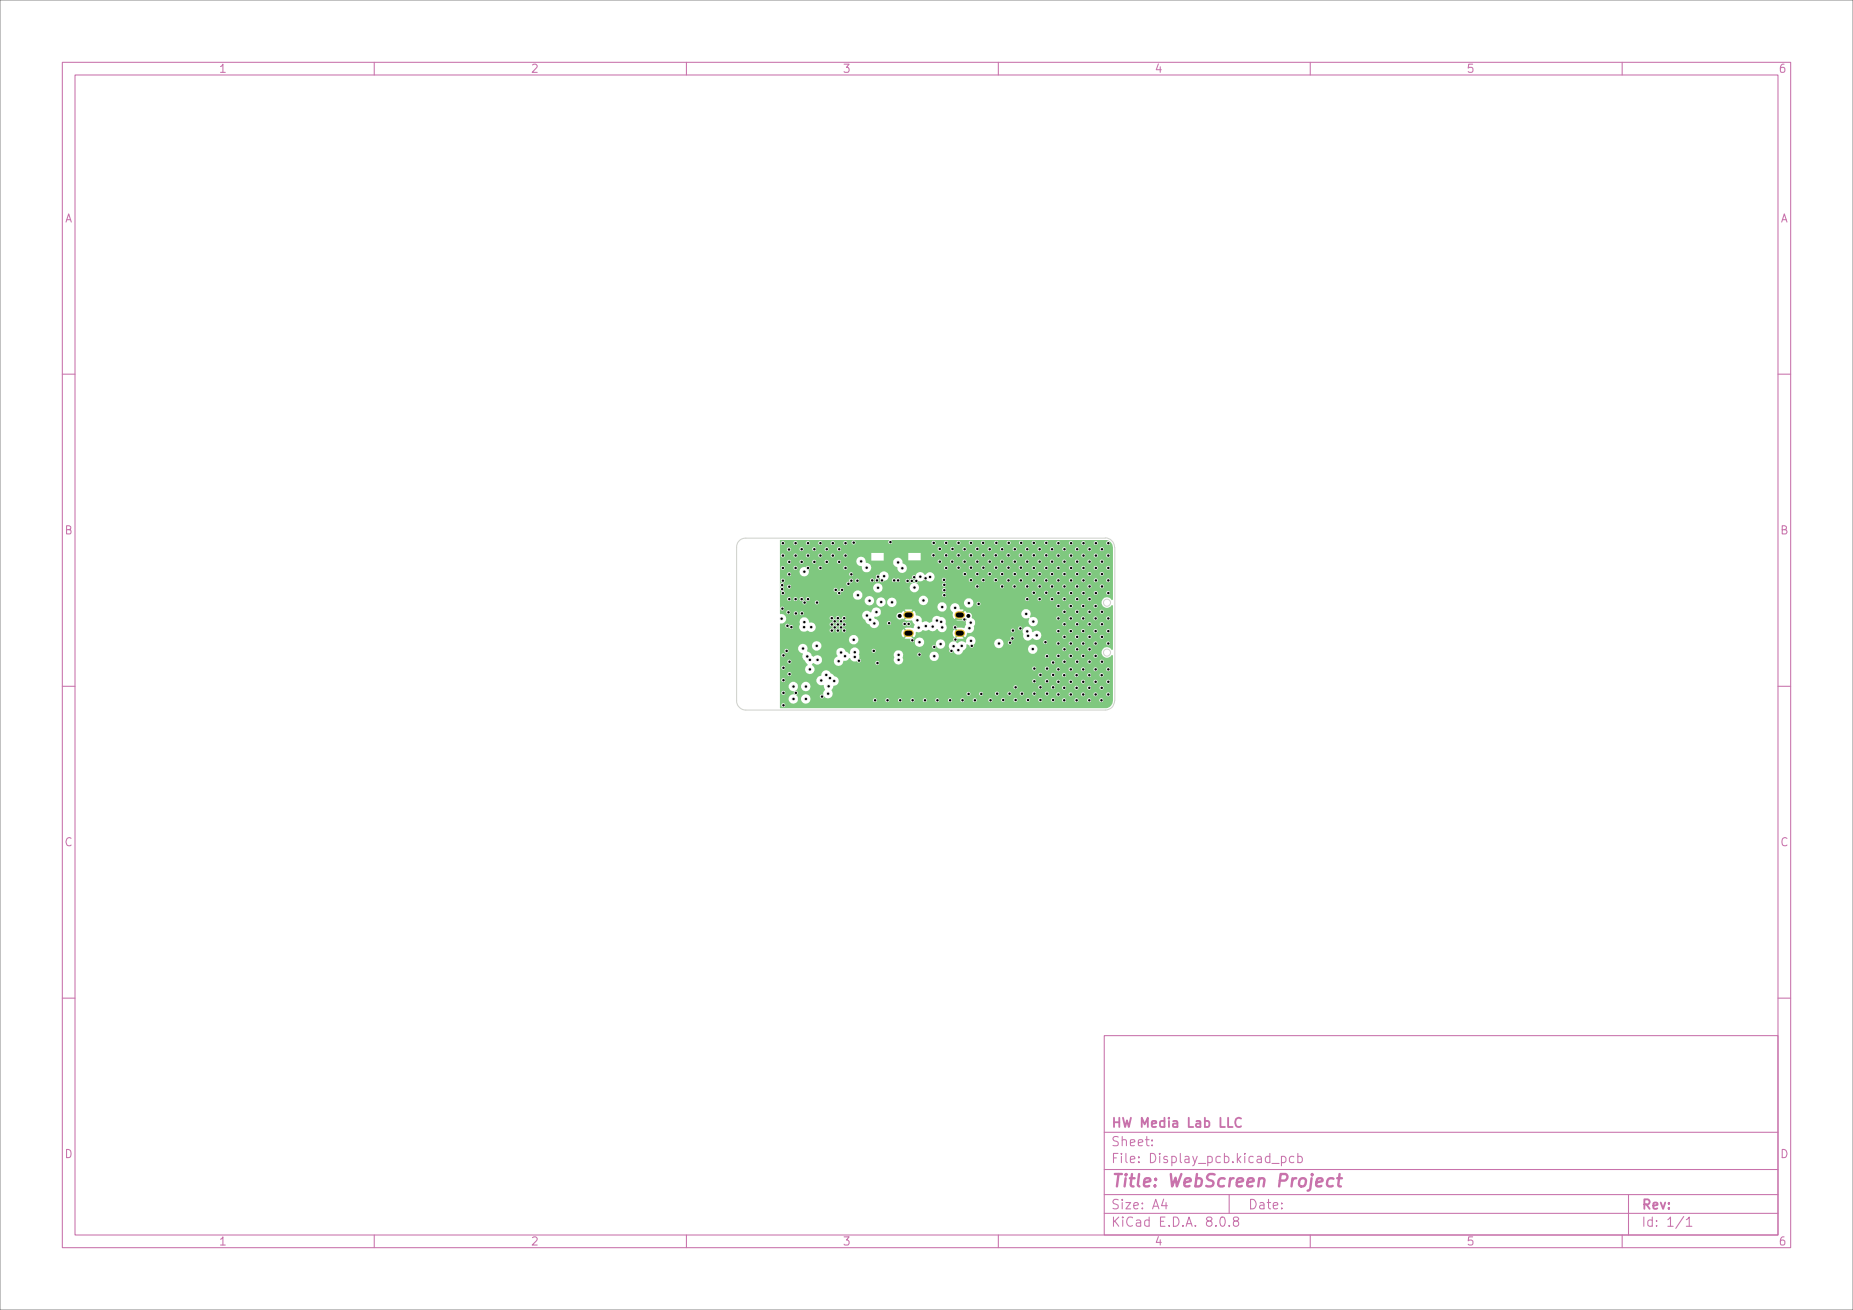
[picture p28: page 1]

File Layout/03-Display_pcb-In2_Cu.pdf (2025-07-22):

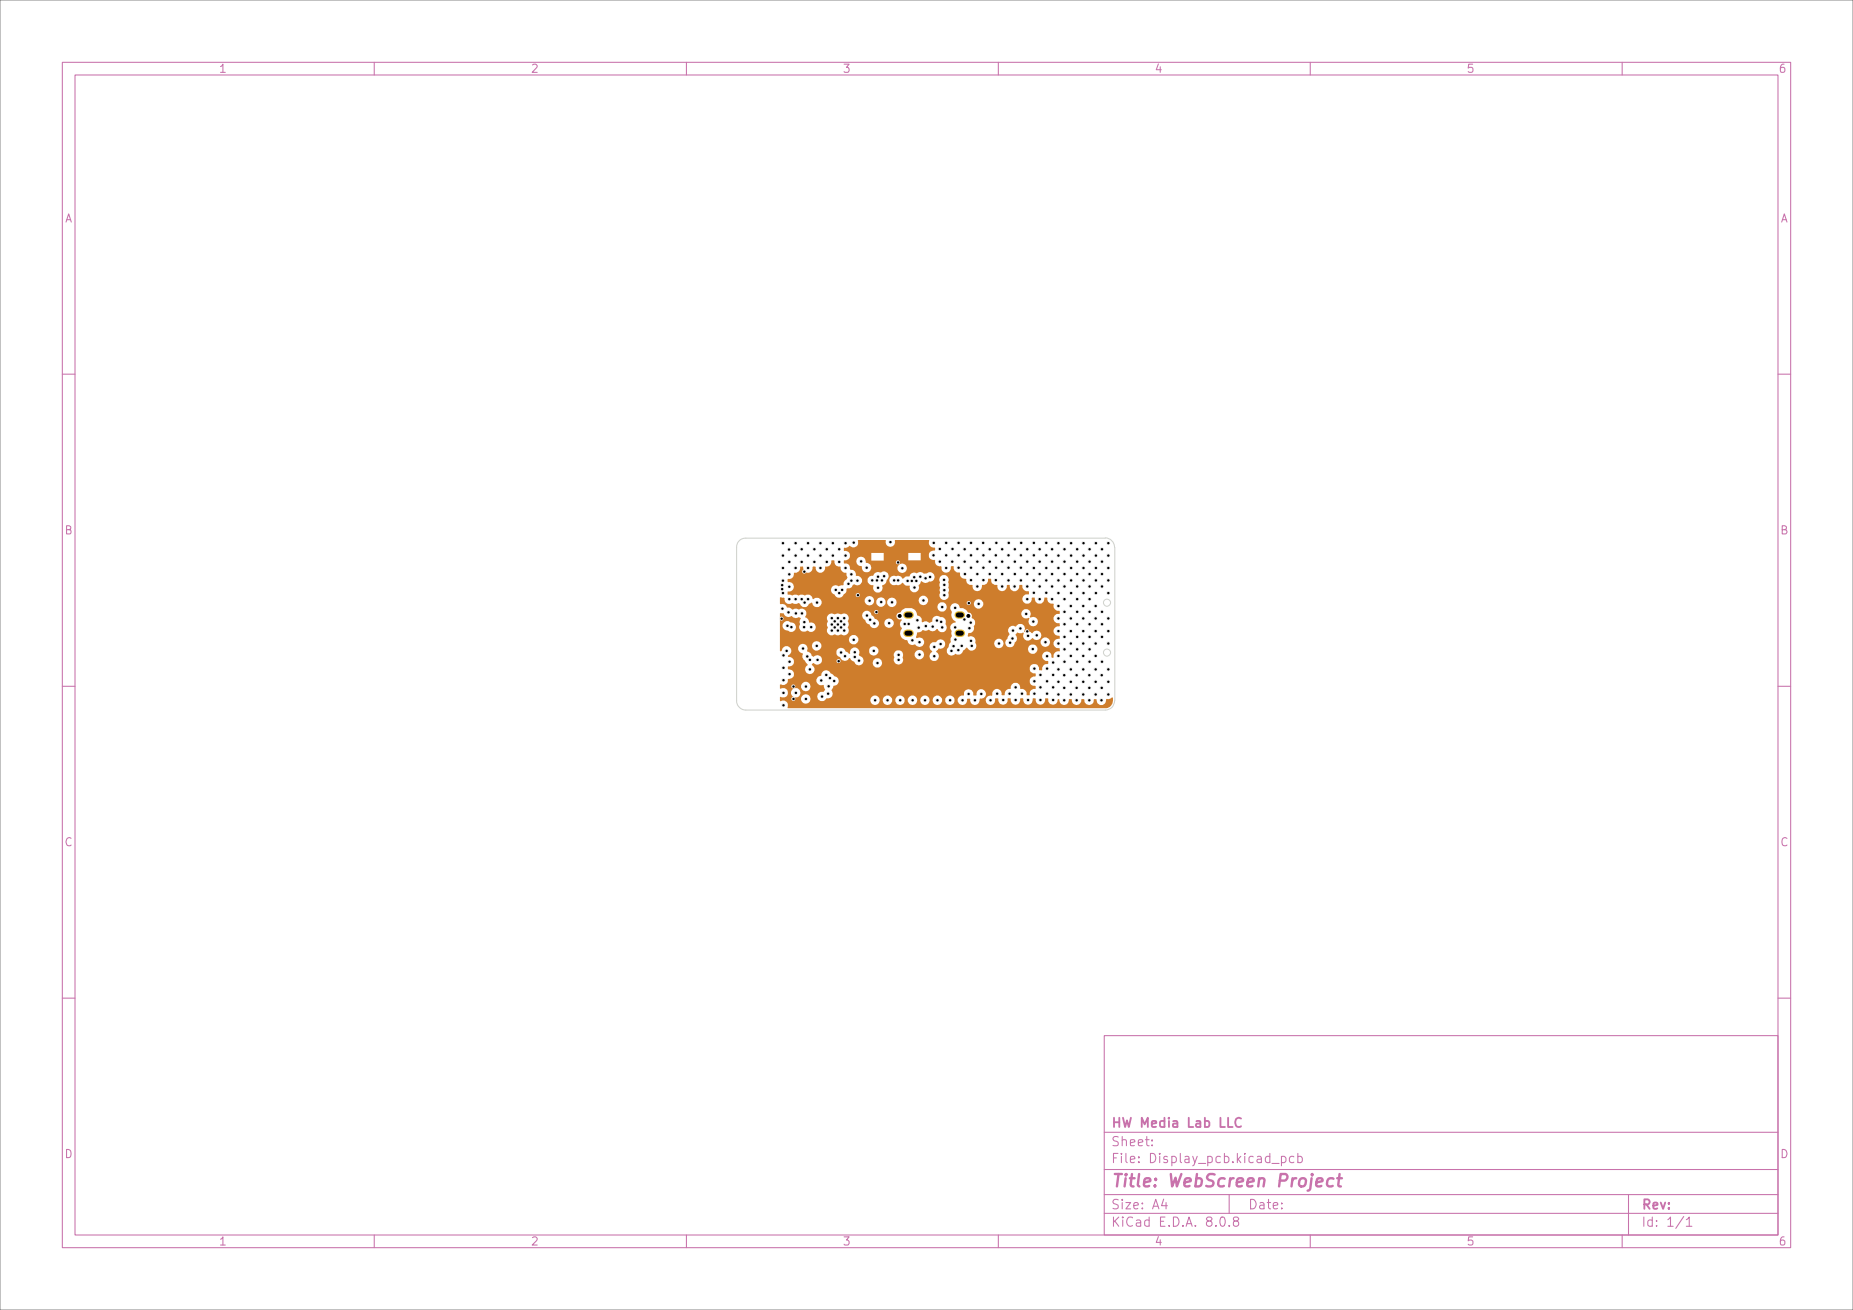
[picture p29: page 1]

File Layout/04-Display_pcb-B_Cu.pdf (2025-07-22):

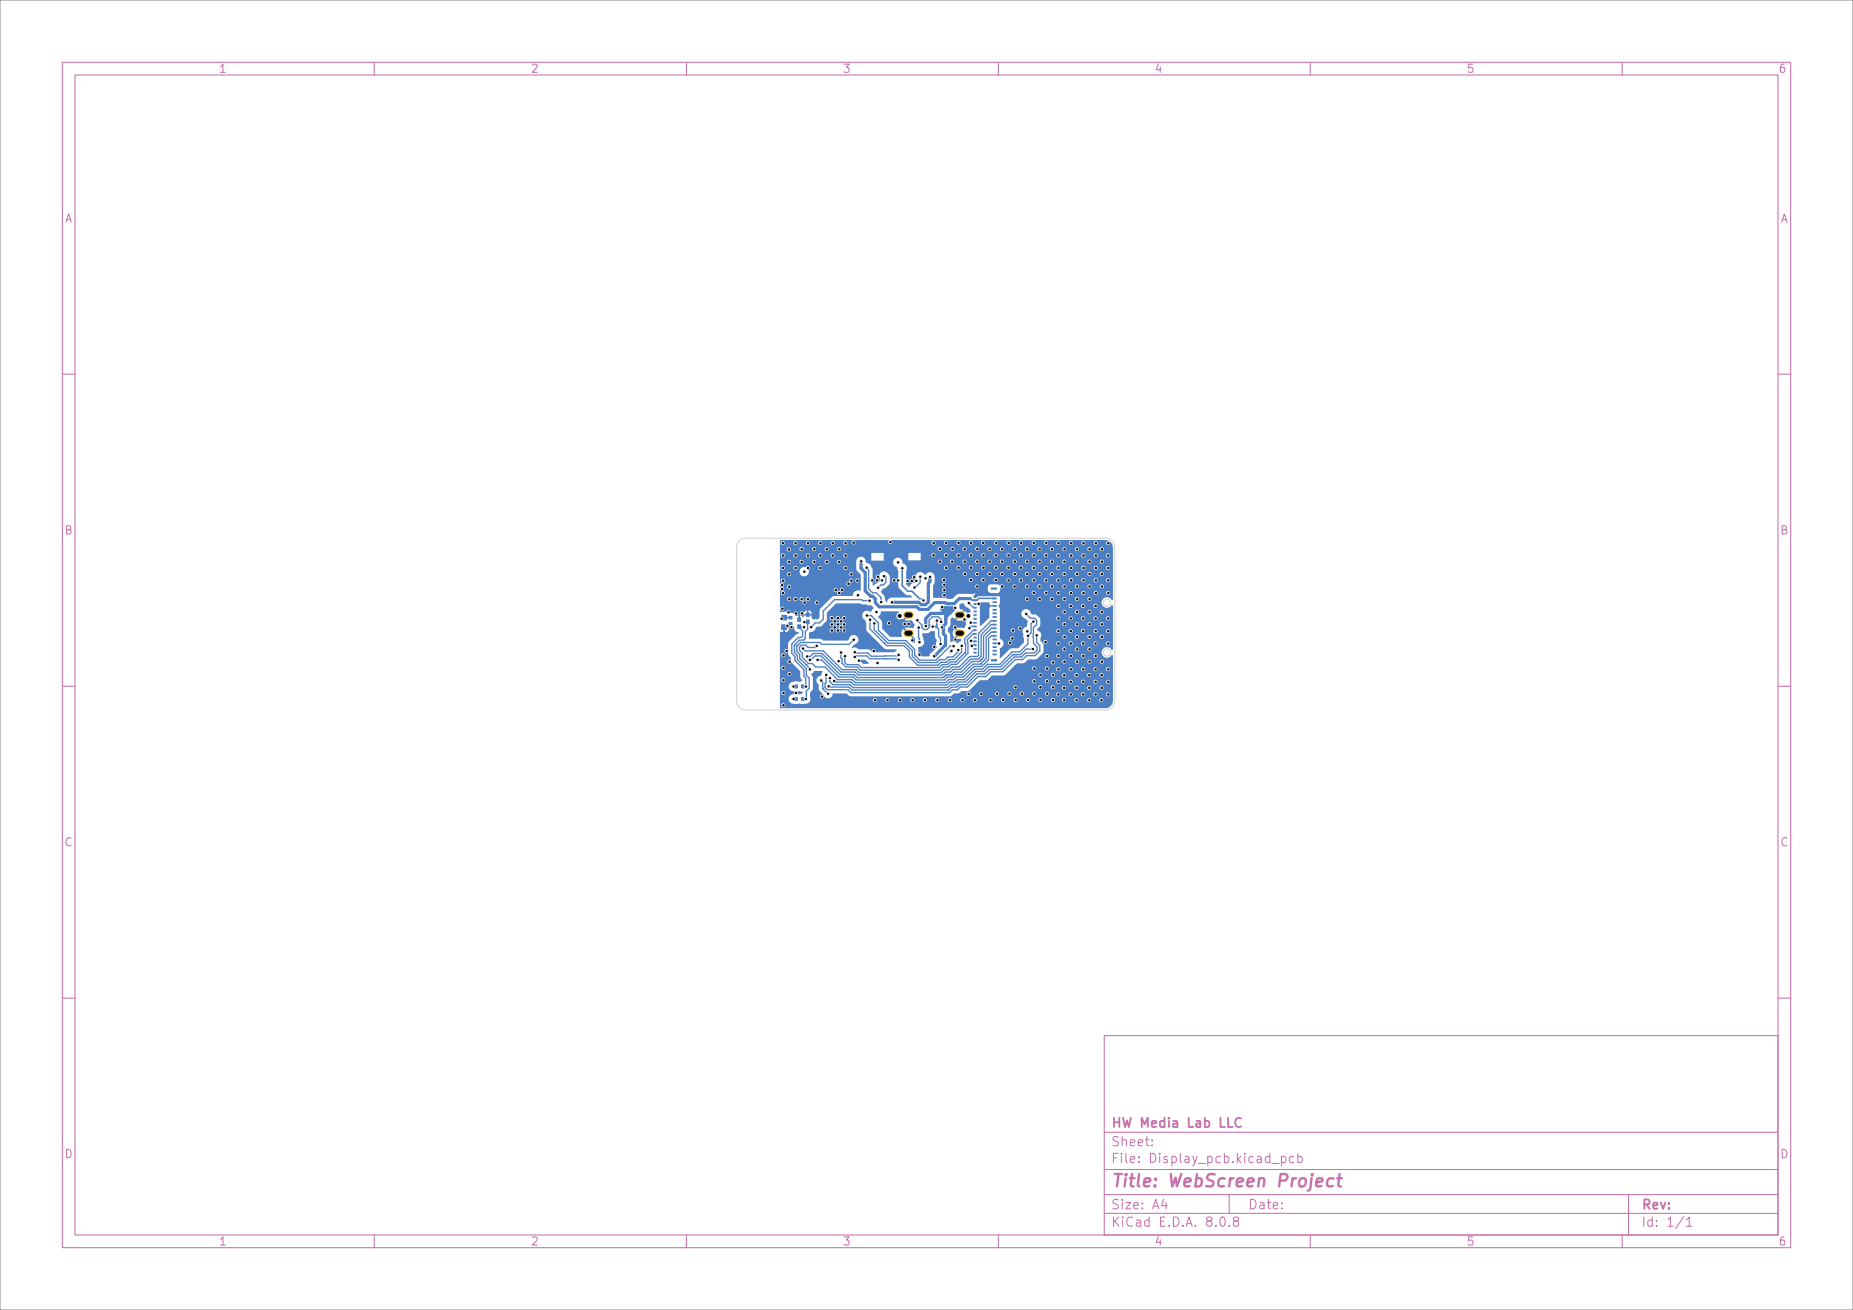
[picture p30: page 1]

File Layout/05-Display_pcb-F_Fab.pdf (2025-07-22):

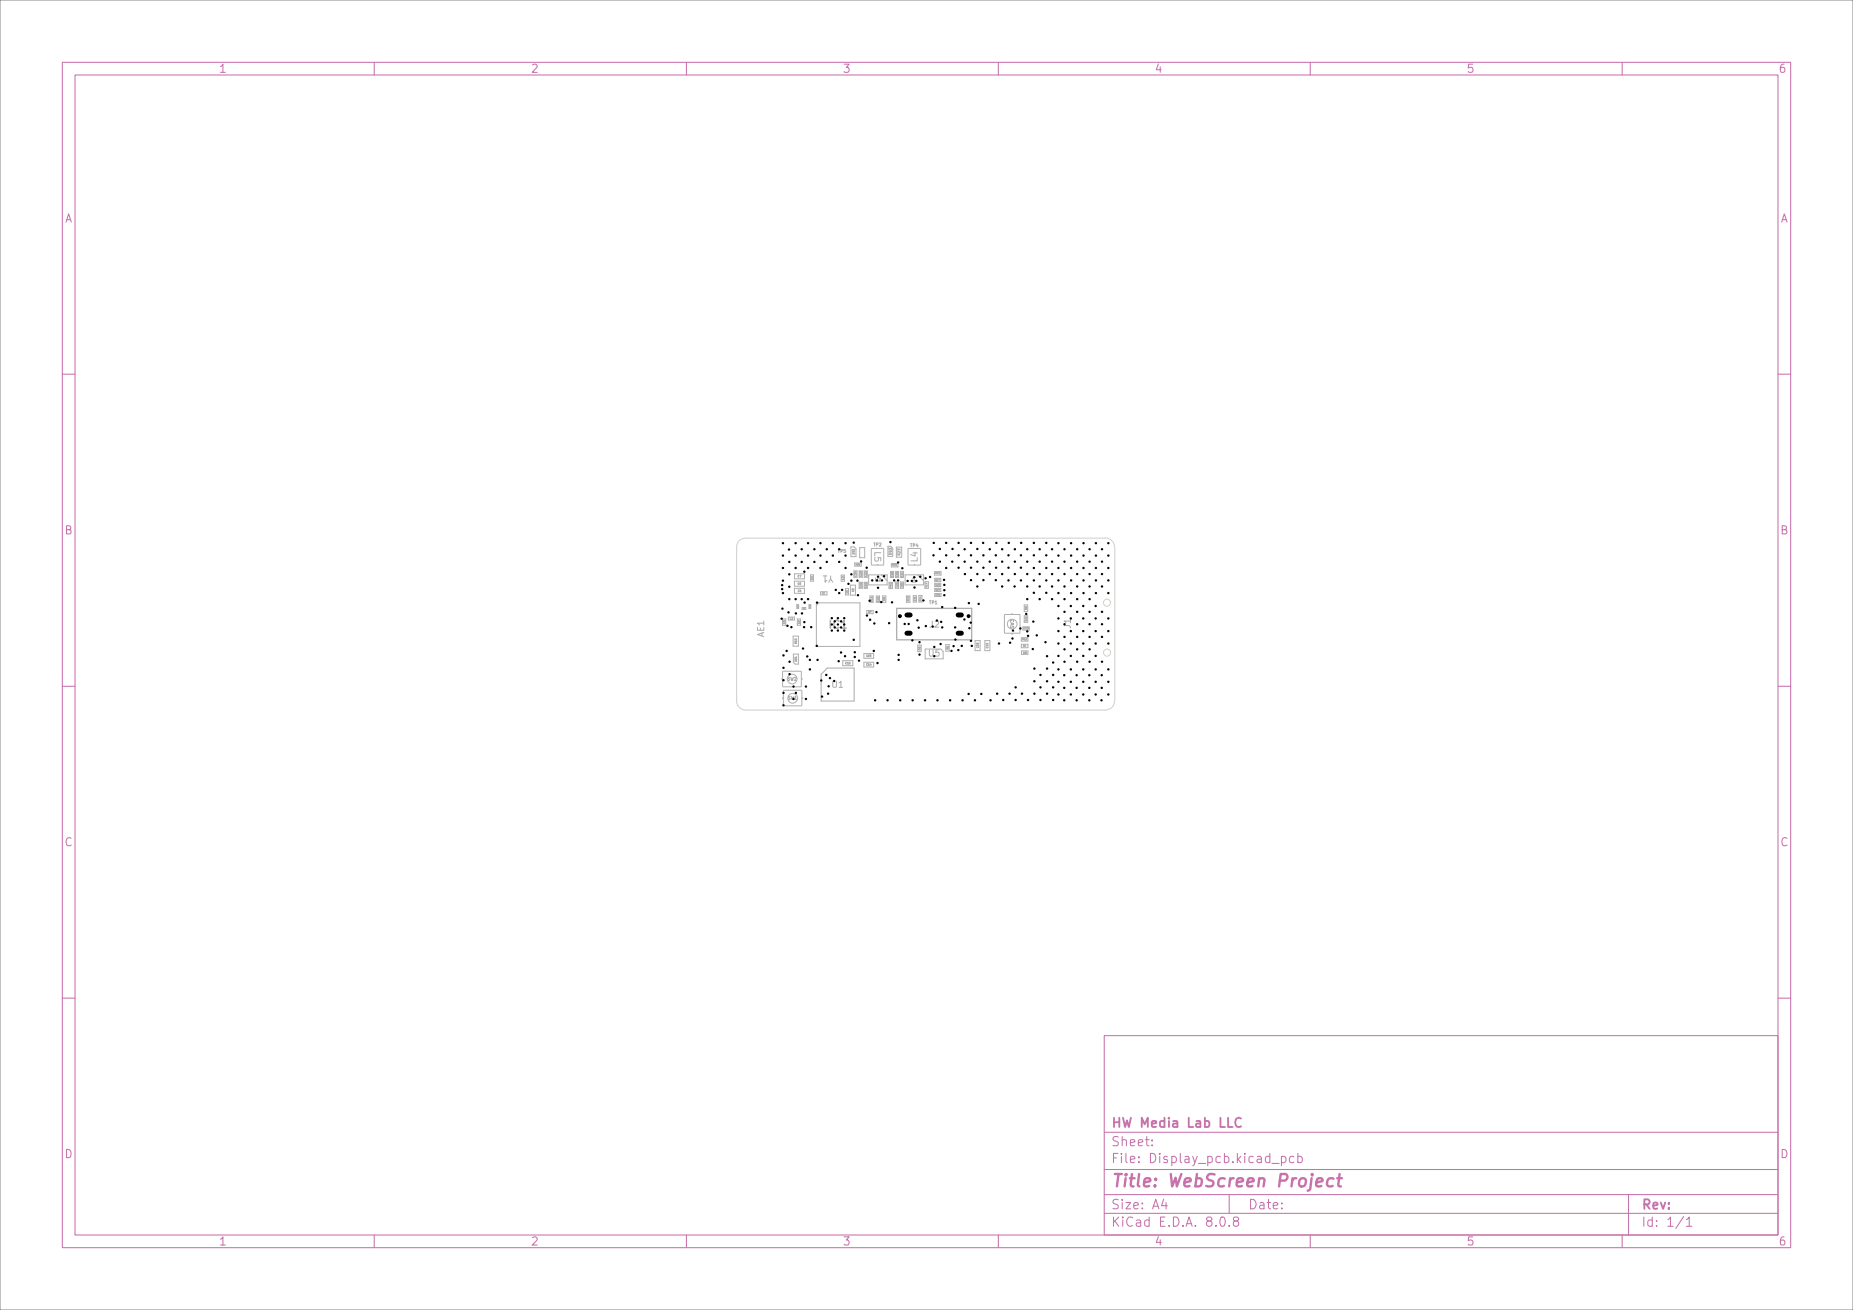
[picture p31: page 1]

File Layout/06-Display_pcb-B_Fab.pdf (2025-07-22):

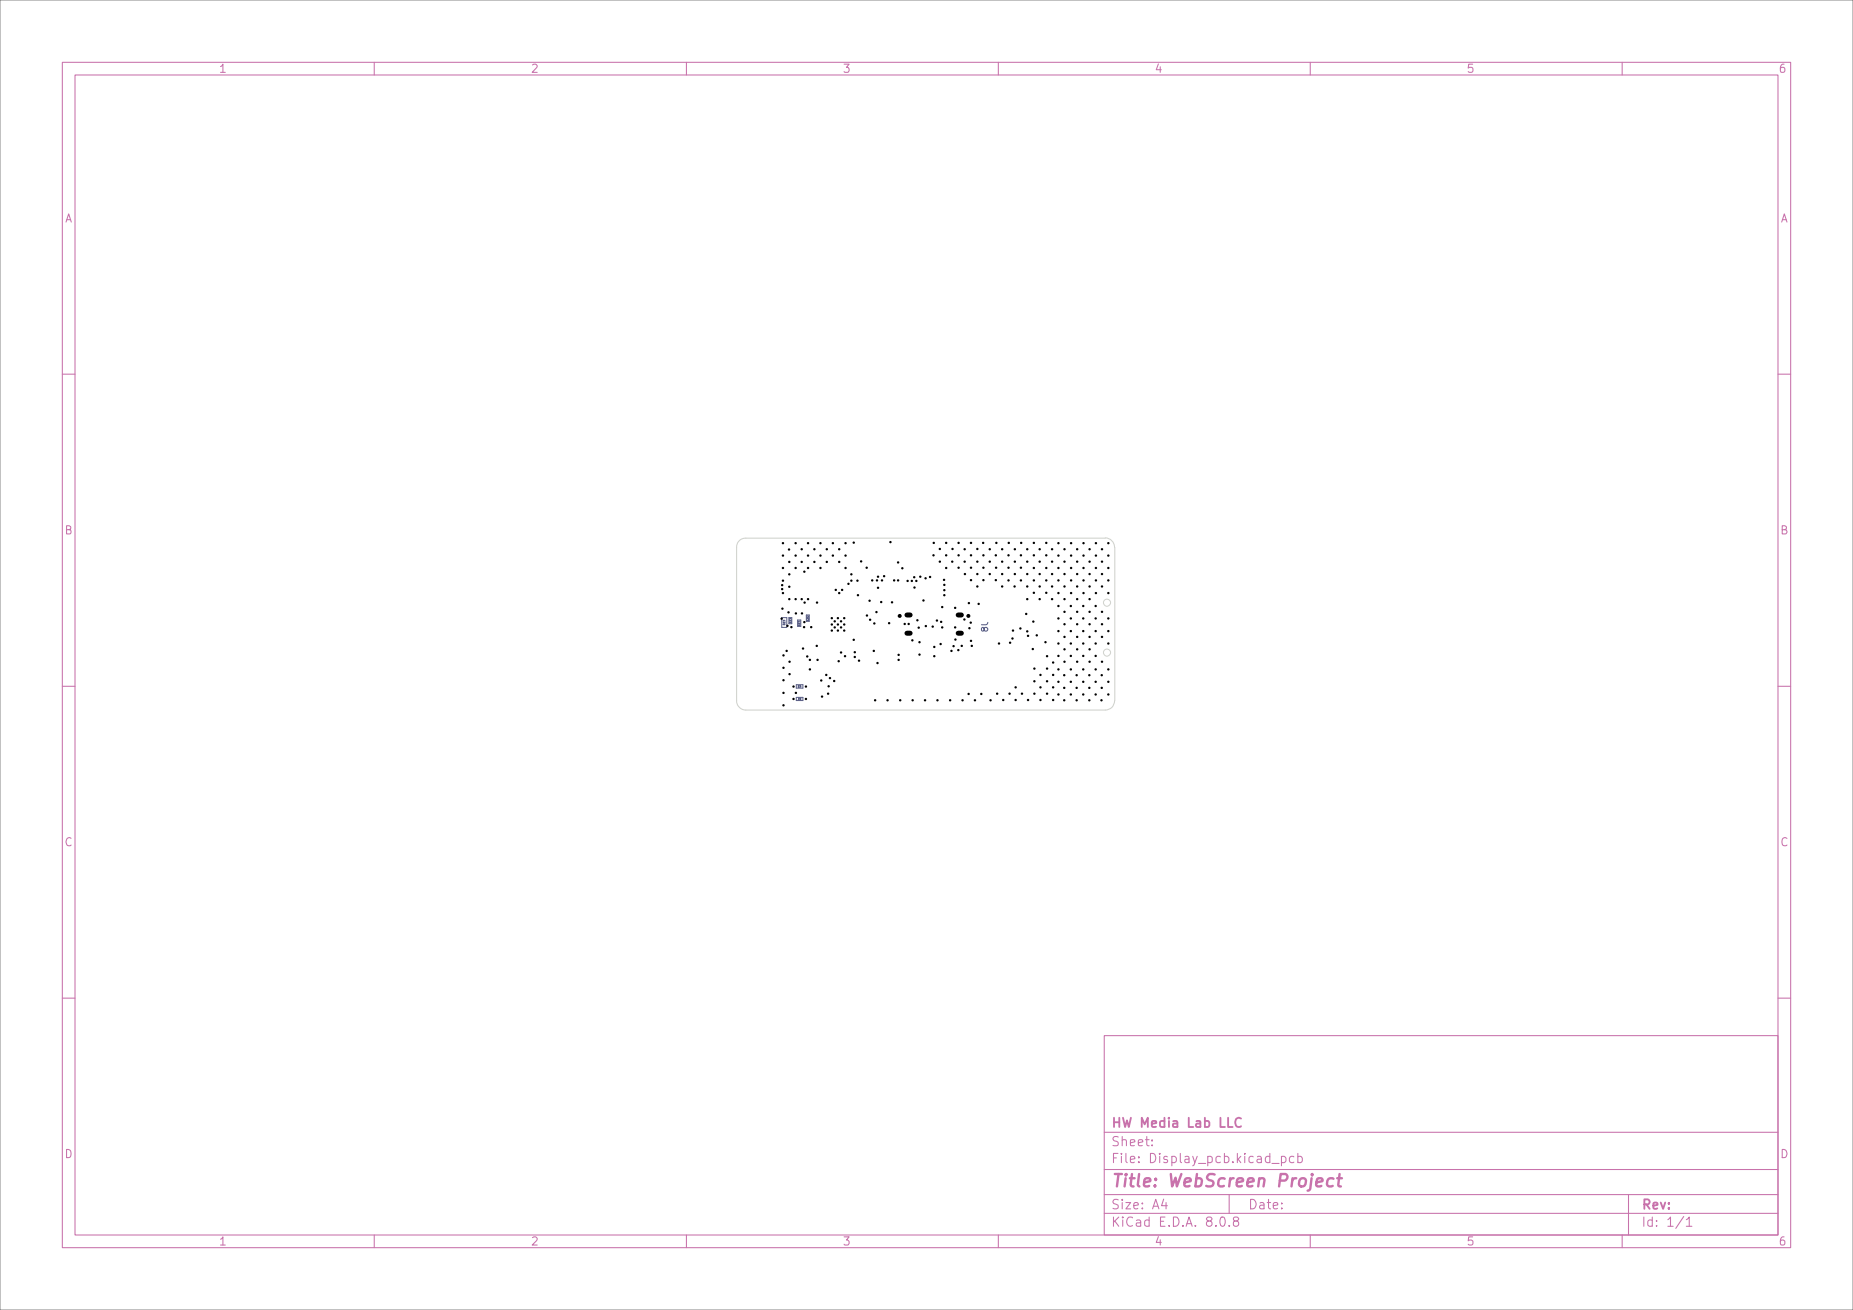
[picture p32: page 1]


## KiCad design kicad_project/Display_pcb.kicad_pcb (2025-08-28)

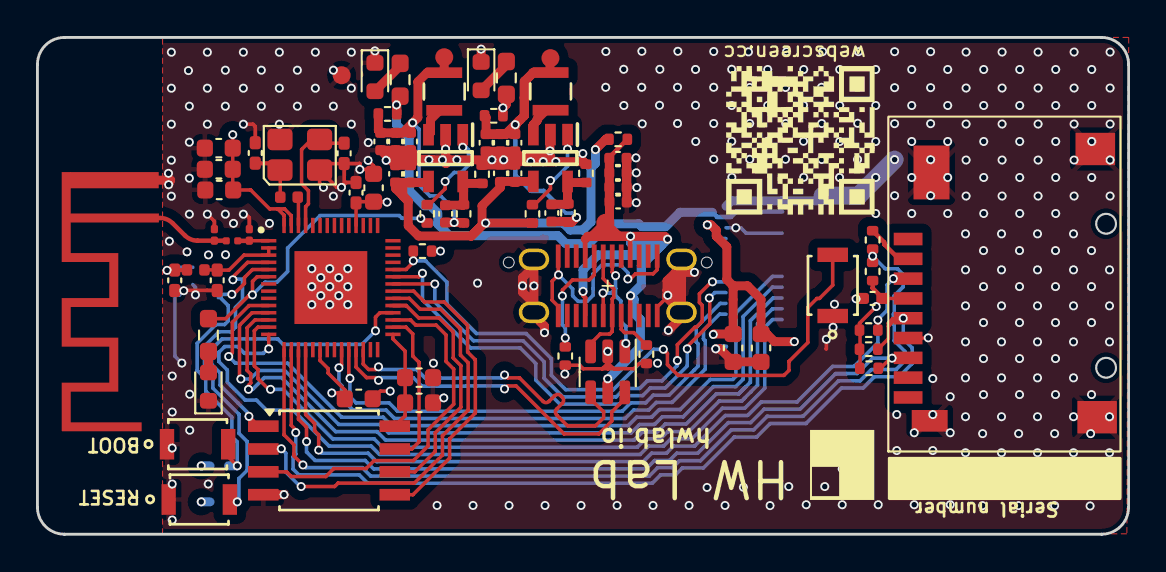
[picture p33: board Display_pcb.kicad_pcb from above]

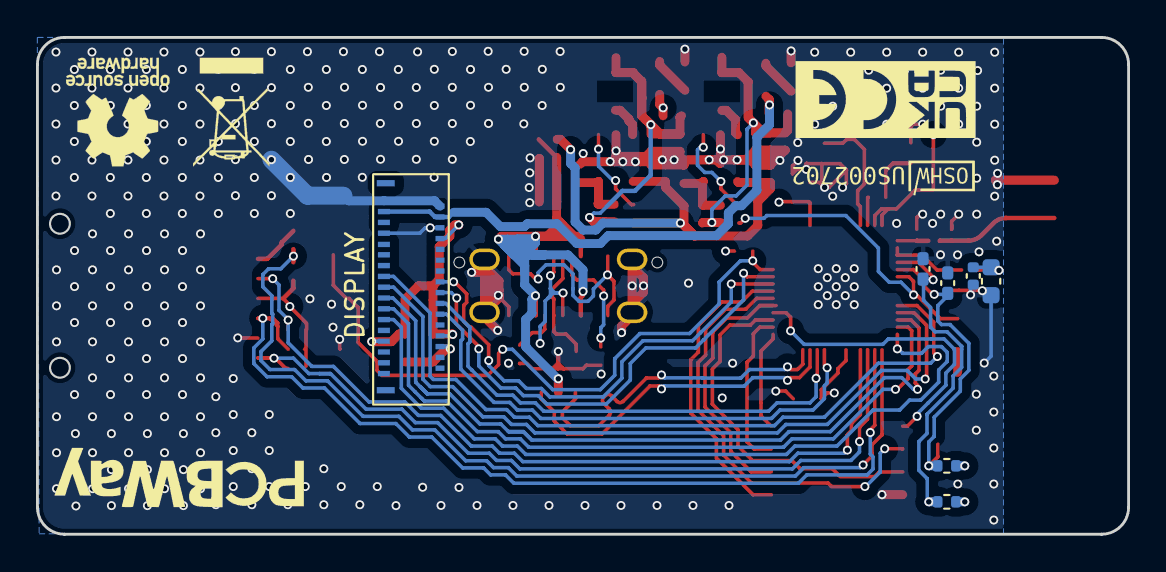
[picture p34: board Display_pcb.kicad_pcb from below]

Board: 4 copper layers, 60.6 x 27.6 mm, 86 parts (7 on the bottom side), 56 nets.

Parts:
AE1: PCB Antenna 2.4GHz; pcb_antenna_2_4GHz
C1, C8, C9, C12, C13, C19: 100nF; C_0402_1005Metric_Pad0.74x0.62mm_HandSolder
C2, C5, C6, C7, C10, C14, C15, C20, C32, C33: 1uF; C_0603_1608Metric
C3: 15pF; C_0402_1005Metric_Pad0.74x0.62mm_HandSolder
C4: 12pF; C_0402_1005Metric_Pad0.74x0.62mm_HandSolder
C11: 10uF; C_0402_1005Metric
C16, C17: 1.8pF; C_0201_0603Metric
C18, C22, C24, C25, C27, C28, C30, C34, C36, C37: 22uF; C_0402_1005Metric
C21, C31: 6.8pF; C_0402_1005Metric
C23, C26, C29, C35: 100nF; C_0402_1005Metric
DS1, DS2, DS3: GREEN; LED_0603_1608Metric
IC1: ESP32-S3R8; QFN40P700X700X90-57N-D
J1: Micro_SD_Card_Det_Hirose_DM3AT; TF PUSH
J2: USB C; USB_C_Receptacle_HCTL_HC019-1E1H1A103-0HR
J8: 33FXRH-SM1-GAN-TF
L1: 22nH; L_0402_1005Metric
L2: 2nH; L_0402_1005Metric
L3: 2.7nH; L_0201_0603Metric
L4, L5: 1uH; BR2518_YDN
NT1, NT2: NetTie_2; NetTie-2_SMD_Pad0.5mm
R1, R2, R3, R4, R7, R10, R12, R20: 10k; R_0402_1005Metric
R5, R6: 4k99; R_0402_1005Metric
R8, R18, R19, R32: 0R; R_0402_1005Metric
R9: 64k9; R_0402_1005Metric
R11, R13, R14: 100k; R_0402_1005Metric
R15, R16, R23: 1k; R_0603_1608Metric_Pad0.98x0.95mm_HandSolder
R17: 22k; R_0402_1005Metric
SW1, SW2, SW3: B3U-1000P
TP1: +5V; TestPoint_Pad_D1.0mm
TP2: +4V6; TestPoint_Pad_D1.0mm
TP4: +3V3; TestPoint_Pad_D1.0mm
TP5: GND; TestPoint_Pad_D1.0mm
U1: W25Q128JVSIQ; SOIC-8W_5.3x5.3mm_P1.27mm
U2, U4: SY8089A1AAC; SOT95P285X130-5N
U5: USBLC6-2SC6; SOT-23-6
Y1: 40MHz; SMD32324-4P

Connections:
4.6V: J8.3, J8.4, R16.2, R32.2
+3V3: C1.1, C2.1, C5.1, C6.1, C7.1, C9.1, C10.1, C11.1, C13.1, C15.1, IC1.20 (VDD3P3_RTC), IC1.46 (VDD3P3_CPU), IC1.55 (VDDA_1), IC1.56 (VDDA_2), J1.4 (VDD), J8.8, L2.1, NT1.2, NT2.2, R1.1, R2.1, R3.1, R4.1, R7.1, R12.1, R18.2, R20.1, R23.2
/AVDD: C32.1, J8.27, NT1.1
/CLK: IC1.16 (GPIO11), J1.5 (CLK), R4.2
/CMD: IC1.18 (GPIO13), J1.3 (CMD), R12.2
/CS: IC1.15 (GPIO10), R8.2, R20.2
/D+: J2.A6 (D+), J2.B6 (D+), U5.3 (I/O2)
/D-: J2.A7 (D-), J2.B7 (D-), U5.1 (I/O1)
/DAT0: IC1.17 (GPIO12), J1.7 (DAT0), R3.2
/Flash_Memory/SPICLK: IC1.33 (SPICLK), U1.6 (CLK)
/Flash_Memory/SPICS0: IC1.32 (SPICS0), U1.1 (~CS)
/Flash_Memory/SPID: IC1.35 (SPID), U1.5 (DI(IO0))
/Flash_Memory/SPIHD: IC1.30 (SPIHD), U1.7 (IO3)
/Flash_Memory/SPIQ: IC1.34 (SPIQ), U1.2 (DO(IO1))
/Flash_Memory/SPIWP: IC1.31 (SPIWP), U1.3 (IO2)
/MCU/GPIO0: C19.1, IC1.5 (GPIO0), R2.2, SW2.2
/MCU/GPIO1: IC1.6 (GPIO1), R11.2, R15.2
/MCU/GPIO33: IC1.38 (GPIO33), R7.2, SW3.2
/MCU/LNA: C16.1, IC1.1 (LNA_IN), L3.2
/MCU/LNA_IN: AE1.1 (FP), C17.1, L3.1
/OL_CS: IC1.11 (GPIO6), J8.17
/OL_D0: IC1.24 (GPIO18), J8.20
/OL_D1: IC1.12 (GPIO7), J8.19
/OL_D2: IC1.36 (SPICLK_N), J8.16
/OL_D3: IC1.10 (GPIO5), J8.15
/OL_RESET: IC1.23 (GPIO17), J8.22
/OL_SCK: IC1.37 (SPICLK_P), J8.18
/OL_SD0: IC1.13 (GPIO8), J8.21
/OL_TE: IC1.14 (GPIO9), J8.23
/POWER/VBUS: C18.1, C27.1, C28.1, C37.1, J2.A4 (VBUS), J2.A9 (VBUS), J2.B4 (VBUS), J2.B9 (VBUS), R19.1, TP1.1, U5.5 (VBUS)
/USB+: IC1.26 (GPIO20), U5.4 (I/O2)
/USB-: IC1.25 (GPIO19), U5.6 (I/O1)
GND: AE1.2 (GND), C1.2, C2.2, C3.2, C4.2, C5.2, C6.2, C7.2, C8.2, C9.2, C10.2, C11.2, C12.2, C13.2, C14.2, C15.2, C16.2, C17.2, C18.2, C19.2, C20.2, C22.2, C23.2, C24.2, C25.2, C26.2, C27.2, C28.2, C29.2, C30.2, C32.2, C33.2, C34.2, C35.2, C36.2, C37.2, DS1.1 (K), DS2.1 (K), DS3.1 (K), IC1.57 (EP), J1.6 (VSS), J1.11 (SHIELD), J2.A1 (GND), J2.S1 (SHIELD), J8.1, J8.2, J8.6, J8.7, J8.28, R5.2, R6.2, R10.2, R17.2, SW1.1, SW2.1, SW3.1, TP5.1, U1.4 (GND), U2.2 (GND), U4.2 (GND), U5.2 (GND), Y1.2, Y1.4
unnamed: C4.1, L1.1, Y1.1
unnamed: C21.1, C22.1, C23.1, C24.1, L5.2, R9.1, R32.1, TP2.1
unnamed: C31.1, C34.1, C35.1, C36.1, L4.2, R14.1, R18.1, TP4.1
unnamed: DS1.2 (A), R15.1
unnamed: DS2.2 (A), R16.1
unnamed: DS3.2 (A), R23.1
unnamed: C12.1, IC1.4 (CHIP_PU), R1.2, SW1.2
unnamed: C8.1, IC1.2 (VDD3P3_1), IC1.3 (VDD3P3_2), L2.2
unnamed: C3.1, IC1.53 (XTAL_N), Y1.3
unnamed: IC1.54 (XTAL_P), L1.2
unnamed: J1.2 (DAT3/CD), R8.1
unnamed: J2.A5 (CC1), R6.1
unnamed: J2.B5 (CC2), R5.1
unnamed: J2.A12 (GND), J2.B1 (GND), J2.B12 (GND)
unnamed: C33.1, J8.26, NT2.1
unnamed: R11.1, U2.1 (EN)
unnamed: C21.2, R9.2, R10.1, U2.5 (FB)
unnamed: L5.1, U2.3 (LX)
unnamed: R13.1, U4.1 (EN)
unnamed: C31.2, R14.2, R17.1, U4.5 (FB)
unnamed: L4.1, U4.3 (LX)
VCC: C25.1, C26.1, C29.1, C30.1, R13.2, R19.2, U2.4 (IN), U4.4 (IN)
VDD_SPI: C14.1, C20.1, IC1.29 (VDD_SPI), U1.8 (VCC)

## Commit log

2024-11-02 Added layout and schematics files.
2024-11-02 Added BOM csv file.
    [WebScreen-BOM.csv]
2024-11-25 Added Kikad profile files.
    [33FXRH-SM1-GAN-TF.STEP, AXPM65611.step, B3U_1000P.step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]
2025-02-19 Pcb to production
    [B3U_1000P.step, D_SMA.step, D_SOD-123.step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]
2025-03-26 Remove USB preregulator from power circuit
    [Display_pcb.kicad_pcb, POWER.kicad_sch, bom.csv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]
2025-06-30 Expose copper on Bluetooth/Wifi antenna (removed front mask)
    [Display_pcb.kicad_pcb, bom.csv, designators.csv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]
2025-07-08 Design revision: SD improvements, flash update, silkscreen and USB differential fix
    [Display_pcb.kicad_pcb, Display_pcb.kicad_sch, flash_memory.kicad_sch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]
2025-07-18 Change SD card power source from VDD_SPI to 3V3 to support A1 cards
    [Display_pcb.kicad_pcb, bom.csv, designators.csv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]
2025-08-26 Add file Technical Note for PCB Manufacturing
2025-08-28 Change logos PcbWay and UK-CA-CE certification
    [Display_pcb.kicad_pcb, designators.csv]

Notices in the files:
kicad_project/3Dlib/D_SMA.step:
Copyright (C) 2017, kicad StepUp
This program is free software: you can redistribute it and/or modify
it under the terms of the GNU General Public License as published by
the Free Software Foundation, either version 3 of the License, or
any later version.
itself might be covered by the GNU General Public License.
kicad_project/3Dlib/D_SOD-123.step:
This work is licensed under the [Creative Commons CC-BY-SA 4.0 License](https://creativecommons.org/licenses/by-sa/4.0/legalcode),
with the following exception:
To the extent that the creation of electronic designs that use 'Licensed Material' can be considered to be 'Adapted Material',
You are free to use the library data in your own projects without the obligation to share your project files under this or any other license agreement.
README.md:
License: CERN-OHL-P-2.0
